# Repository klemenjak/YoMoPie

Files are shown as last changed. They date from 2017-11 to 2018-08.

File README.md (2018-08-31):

# Servus!

Computational methods for the enhancement of energy efficiency rely on a measurement process with sufficient accuracy and number of measurements. Networked energy meters, energy monitors, serve as a vital link between the energy consumption of households and key insights that reveal strategies to achieve significant energy savings.
With YoMoPie, we propose a user-oriented energy monitor for the Raspberry Pi platform that aims to enable intelligent energy services in households. YoMoPie measures active as well as apparent power, stores data locally, and integrates a user-friendly Python library. Furthermore, the presented energy monitor allows users to run self-designed services in their home to enhance energy efficiency. Potential services are (but not limited to) residential demand response, immediate user feedback, smart meter data analytics, or energy disaggregation.

<!--- YoMoPie builds on [the work published in [1]](https://link.springer.com/article/10.1007%2Fs00450-014-0290-8#/page-1).
YoMoPie provides the following advancements:

* It doesn't suffer from a data update rate of 1 second
* It stores data locally
* It integrates a new measurement IC that allows poly-phase metering
* It builds on the Raspberry platform
* The YoMoPie Python package enables easy handling -->

## Research Paper on YomoPie

All design files and pieces of software are available free of charge. However, in case you use the PCB design, code, or other material for research purposes, we kindly ask you to cite our peer-reviewed research paper:

* *Title*: YoMoPie: A User-Oriented Energy Monitor to Enhance Energy Efficiency in Households
* *Authors*: Mr. Christoph Klemenjak, Mr. Stefan Jost and Dr. Wilfried Elmenreich
* *Conference*: 2018 IEEE Conference on Technologies for Sustainability (SusTech)

Recommended Citation:
```
@INPROCEEDINGS{klemenjak2018yomopie,
author={C. Klemenjak and S. Jost and W. Elmenreich},
booktitle={2018 IEEE Conference on Technologies for Sustainability (SusTech)},
title={Yo{M}o{P}ie: {A} User-Oriented Energy Monitor to Enhance Energy Efficiency in Households},
year={2018},
volume={},
number={},
pages={},
keywords={},
doi={},
ISSN={},
month={Nov}}
```

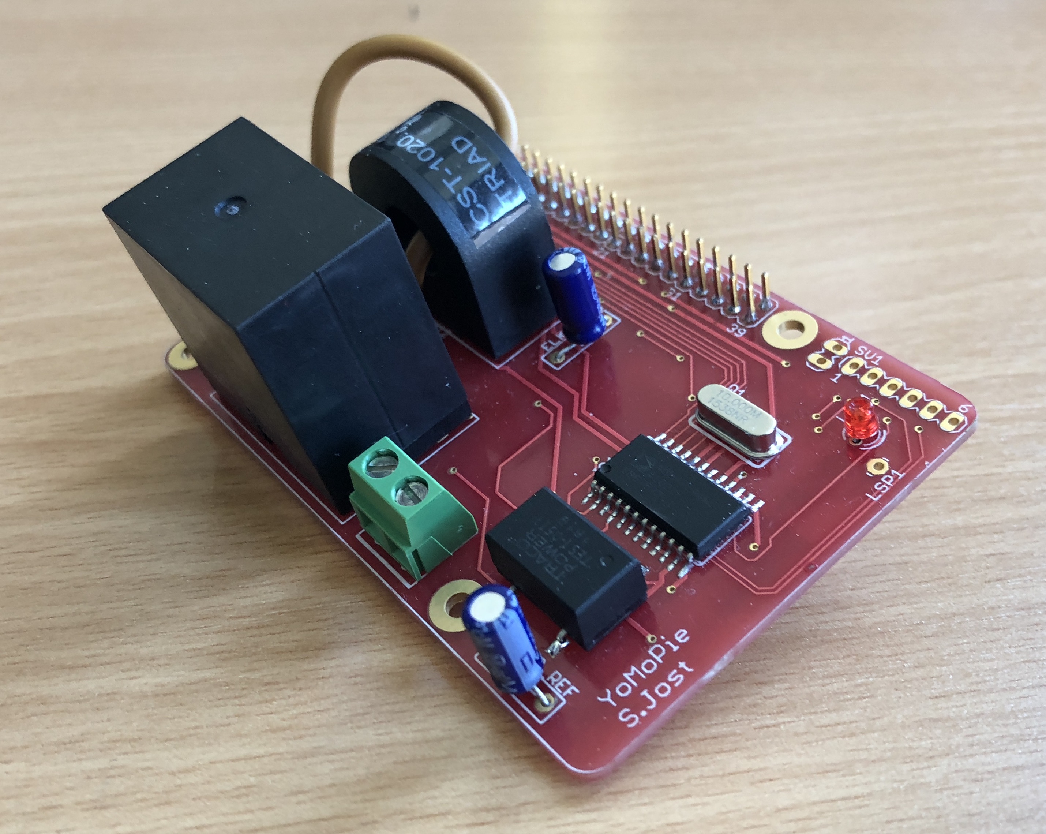
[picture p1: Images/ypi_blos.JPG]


| | YoMoPie  |
| --- | -----:|
|Communication|  WiFi, Ethernet, RF |
|Measurement|  P, Q, S, I, U |
|Number of connections| 1 or 3 |
|Integrated relay |  yes |
|Sampling frequency|  tba. |
|Data update rate |  tba. |
|Power calculation|  Hardware |
|Open-Source|  yes |
|RaspberryPi-compatible|  yes  |
|Costs| approx. 50€  |

Beside a current and a voltage sensor, the board integrates an energy metering chip, the ADE7754. Our library is designed in a way to offer single-phase as well as multi-phase metering.

## Installation

The YoMoPie Python package is available on Python Package Index (PyPI), a repository of software for the Python programming language, and can be installed by issuing one command:

```python
pip3 install YoMoPie
```
Additionally, the entire source code and a manual can be obtained from our YoMoPie Github repository.

## Examples of use

After a successful installation process, the YoMoPie package is available system-wide and can be accessed by a simple import command:
```python
import YoMoPie as yomopie
yp = yomopie.YoMoPie()
```

During initialisation, the number of line conductors has to be set (single or polyphase metering):
```python
yomo.set_lines(1)
```

To test the operation, we recommend to call the function *do_n_measurements*. Based on the number of samples and the sampling period, the function will return first measurement values and saves it into the target file:
```python
yomo.do_n_measurements(number of samples, sampling period, target file)
```

Active power, apparent power, current, and voltage samples can be read with commands such as:
```python
[t, I] = yp.get_irms()
[t, U] = yp.get_vrms()
[t, P] = yp.get_active_energy()
[t, S] = yp.get_apparent_energy()
```
In the same vein, users can activate continuous data logging or perform a fixed amount of subsequent measurements:
```python
yp.do_metering()
yp.do_n_measurements(quantity, rate, file)
```

The operational mode (OPMODE) register defines the general configuration of the integrated measurement chip ADE7754. By writing to this register, A/D converters can be turned on/off, sleep mode can be activated, or a software chip reset can be triggered. For further information, we refer to the datasheet of the measurement chip.

```python
yp.set_operational_mode(OPMODE)
```

# YoMoPie Python package documentation
**[Imports](#imports)**<br>
**[Classvariables](#classvariables)**<br>
**[Methods](#methods)**<br>
*[-init](#init)*<br>
*[-init_yomopie](#init_yomopie)*<br>
*[-set_lines](#set_lines)*<br>
*[-enable_board](#enable_board)*<br>
*[-disable_board](#disable_board)*<br>
*[-chip_reset](#chip_reset)*<br>
*[-write_8bit](#write_8bit)*<br>
*[-read_8bit](#read_8bit)*<br>
*[-write_16bit](#write_16bit)*<br>
*[-read_16bit](#read_16bit)*<br>
*[-read_24bit](#read_24bit)*<br>
*[-get_temp](#get_temp)*<br>
*[-get_laenergy](#get_laenergy)*<br>
*[-get_lappenergy](#get_lappenergy)*<br>
*[-get_period](#get_period)*<br>
*[-set_operational_mode](#set_operational_mode)*<br>
*[-set_measurement_mode](#set_measurement_mode)*<br>
*[-close_SPI_connection](#close_SPI_connection)*<br>
*[-get_aenergy](#get_aenergy)*<br>
*[-get_active_energy](#get_active_energy)*<br>
*[-get_apparent_energy](#get_apparent_energy)*<br>
*[-get_sample](#get_sample)*<br>
*[-get_sampleperperiod](#get_sampleperperiod)*<br>
*[-get_vrms](#get_vrms)*<br>
*[-get_irms](#get_irms)*<br>
*[-do_n_measurements](#do_n_measurements)*<br>
*[-do_metering](#do_metering)*<br>
*[-change_factors](#change_factors)*<br>
*[-reset_factors](#reset_factors)*<br>
*[-init_nrf24](#init_nrf24)*<br>
*[-write_nrf24](#write_nrf24)*<br>
*[-read_nrf24](#read_nrf24)*<br>
**[OPMODE](#opmode)**<br>
**[MMODE](#mmode)**<br>

## Imports
YomoPie requires some additional libraries:

**time**: The time package is required to obtain timestamps.

**math**: YoMoPie requires the math lib for calculations such as reactive energy.

**spidev**: The YoMoPie integrates an energy monitor IC, which communicates via SPI to the RPi. To enable this communication, YoMoPie exploits the spidev lib.

**sys**: This module provides access to some variables used or maintained by the interpreter and to functions that interact strongly with the interpreter.

**RPi.GPIO**: In order to allow further extensions of the YoMoPie eco-system, our package integrates the RPi.GPIO. Also, the reset pin is controlled via GPIO.

**NRF24**: This package allows to utilize the RF module for 2.4 GHz communication.

```python
import time
import math
import spidev
import sys
import RPi.GPIO as GPIO
from lib_nrf24 import NRF24
```
## Class variables

To correctly access the internal registers of the energy monitor IC, several custom variables are required to adjust the register values.

* **read** and **write**: These variables hold the mask that defines the operational mode. Therefore, for reading a register the given address and the **read** variable are the inputs of a bitwise AND operation. On the other hand, for writing to a register the register address and the **write** variable are the inputs of a bitwise OR operation.

* **spi**, **active_lines** and **debug**: These variables hold the SPI object, save the number of active lines, and enable/disable the debug mode.

* **radio**: This object will be used for the RF communication and its functions.
* **sample interval** and **max_f_sample**: defines the time between two samples (with respect to the start_sampling method) in seconds and the maximum sampling frequency (with respect to the sampling error).
* **active_power_LSB**, **apparent_power_LSB**, **vrms_factor** and **irms_factor**: Convert register values to physical quantities and represent permanent conversion factors.

```python
read = 0b00111111
write = 0b10000000
spi=0
radio=0
active_lines = 1
debug = 1

sample_intervall = 1
max_f_sample = 10

active_power_LSB= 0.000013292
apparent_power_LSB= 0.00001024
vrms_factor = 0.000047159
irms_factor = 0.000010807
```

## Methods

In this Section, we describe every method of our  package. A description of function parameters and return values is given.

### __init__

**Description**: This method represents  the constructor and creates a new YoMoPie object.

**Parameters**: None.

**Returns**: Nothing.

```python
def __init__(self):
	self.spi=spidev.SpiDev()
	self.init_yomopie()
	return
```

### init_yomopie

**Description**: Initialises the YoMoPie object. Sets the GPIO mode, disables GPIO warnings and defines pin 19 as output. Also opens a new SPI connection via the SPI device (0,0), sets the SPI speed to 62500 Hz and sets the SPI mode to 1. Finally, the function set_lines is called to set the MMODE, WATMODE and VAMODE.

**Parameters**: None.

**Returns**: Nothing.

```python
def init_yomopie(self):
	GPIO.setmode(GPIO.BCM)
	GPIO.setwarnings(False)
	GPIO.setup(19,GPIO.OUT)
	self.spi.open(0,0)
	self.spi.max_speed_hz = 62500
	self.spi.mode = 0b01
	self.set_lines(self.active_lines)
	self.sampleintervall = 1
	return
```

### set_lines

**Description**: This function sets the number of active phases that will be measured.

**Parameters**:
* lines - Number of phases

**Returns**: Nothing.

```python
def set_lines(self, lines):
	if (lines != 1) and (lines != 3):
		print("Incompatible number of power lines")
		return
	else:
		self.active_lines = lines
		if self.active_lines == 3:
			self.write_8bit(0x0D, 0x3F)
			self.write_8bit(0x0E, 0x3F)
			self.set_measurement_mode(0x70)
		elif self.active_lines == 1:
			self.write_8bit(0x0E, 0x24)
			self.set_measurement_mode(0x10)
			self.write_8bit(0x0D, 0x24)
		return
```

### enable_board

**Description**: Enables the board by pulling pin 19 to HIGH.

**Parameters**: None.

**Returns**: Nothing.

```python
def enable_board(self):
	GPIO.output(19, GPIO.HIGH)
	return
```

### disable_board

**Description**: Disables the board by pulling pin 19 to LOW.

**Parameters**: None.

**Returns**: Nothing.

```python
def disable_board(self):
	GPIO.output(19, GPIO.LOW)
	return
```

### chip_reset

**Description**: Resets the chip to the manufacturer settings

**Parameters**: None.

**Returns**: Nothing.

```python
def chip_reset(self):
	self.write_8bit(0x0A, 0x40)
	time.sleep(1);
	return
```		
### write_8bit    

**Description**: Writes 8 bit to the given address.

**Parameters**:

* register - 8 bit address of the register (see ADE7754 register table)

* value - 8 bit of value that will be written into the register

**Returns**: Nothing.

```python
def write_8bit(self, register, value):
	self.enable_board()
	register = register | self.write
	self.spi.xfer2([register, value])
	return
```

### read_8bit

**Description**: Reads 8 bit of data from the given address.

**Parameters**:
* register - 8 bit address of the register (see ADE7754 register table)

**Returns**: the 8 bit of data in the register as decimal

```python
def read_8bit(self, register):
	self.enable_board()
	register = register & self.read
	result = self.spi.xfer2([register, 0x00])[1:]        
	return result[0]
```

### write_16bit

**Description**: Writes 16 bit to the given address.

**Parameters**:

* register - 8 bit address of the register (see ADE7754 register table)

* value - 16 bit of value that will be written into the register

**Returns**: Nothing.

```python
def write_16bit(self, register, value):
	self.enable_board()
	register = register | self.write
	self.spi.xfer2([register, value[0], value[1]])
	return
```		

### read_16bit  

**Description**: Reads 16 bit of data from the given address.

**Parameters**:
* register - 8 bit address of the register (see ADE7754 register table)

**Returns**: the 16 bit of data in the register as decimal

```python
def read_16bit(self, register):
	self.enable_board()
	register = register & self.read
	result = self.spi.xfer2([register, 0x00, 0x00])[1:]
	dec_result = (result[0]<<8)+result[1]
	return dec_result
```

### read_24bit        

**Description**: Reads 24 bit of data from the given address.

**Parameters**:
* register - 8 bit address of the register (see ADE7754 register table)

**Returns**: the 24 bit of data in the register as decimal

```python
def read_24bit(self, register):
	self.enable_board()
	register = register & self.read
	result = self.spi.xfer2([register, 0x00, 0x00, 0x00])[1:]
	dec_result = (result[0]<<16)+(result[1]<<8)+(result[2])
	return dec_result
```

### get_temp

**Description**: Reads the temperature register (0x08).

**Parameters**: None.

**Returns**: A list [timestamp, temperature in °C]

```python
def get_temp(self):
	reg = self.read_8bit(0x08)
	temp = [time.time(),(reg-129)/4]
	return temp
```

### get_laenergy

**Description**: Reads the active energy register (0x03).

**Parameters**: None.

**Returns**: A list [timestamp, value of the register]

```python
def get_laenergy(self):
	laenergy = [time.time(), self.read_24bit(0x03)]
	return laenergy
```

### get_lappenergy

**Description**: Reads the apparent energy register (0x06).

**Parameters**: None.

**Returns**: A list [timestamp, value of the register]

```python
def get_lappenergy(self):
	lappenergy = [time.time(), self.read_24bit(0x06)]
	return lappenergy
```

### get_period   

**Description**: Reads the period register (0x07).

**Parameters**: None.

**Returns**: A list [timestamp, value of the register]

```python
def get_period(self):
       period = [time.time(), self.read_16bit(0x07)]
       return period
```

### set_operational_mode

**Description**: Sets the OPMODE. For more information see section OPMODE.

**Parameters**:
* value - 8 bit of data representing the OPMODE

**Returns**: Nothing.

```python
def set_operational_mode(self, value):
	self.write_8bit(0x0A, value)
	return
```

### set_measurement_mode

**Description**: Sets the MMODE. For more information see section MMODE.

**Parameters**:
* value - 8 bit of data representing the MMODE

**Returns**: Nothing.

```python
def set_measurement_mode(self, value):
	self.write_8bit(0x0B, value)
	return
```

### close_SPI_connection

**Description**: Closes the SPI connection.

**Parameters**: None.

Returns**: 0 if connection is closed.

```python
def close_SPI_connection(self):
	self.spi.close()
	return 0
```
### get_aenergy

**Description**: Reads the active energy register (0x01).

**Parameters**: None.

**Returns**: A list [timestamp, value of register converted to real value]

```python
def get_aenergy(self):
	aenergy = [time.time(), self.active_power_LSB * self.read_24bit(0x01) *  3600/self.sample_intervall]
	return aenergy
```
### get_active_energy

**Description**: Reads the active energy register (0x02) and resets the register value.

**Parameters**: None.

**Returns**: A list [timestamp, value of register converted to real value]

```python
def get_active_energy(self):
	aenergy =  [time.time(), self.active_power_LSB * self.read_24bit(0x02) *  3600/self.sample_intervall]
	return aenergy
```
### get_apparent_energy

**Description**: Reads the apparent energy register (0x05) and resets the register vlaue.

**Parameters**: None.

**Returns**: A list [timestamp, value of register converted to real value]

```python
def get_apparent_energy(self):
	appenergy = [time.time(), self.apparent_power_LSB * self.read_24bit(0x05)*  3600/self.sample_intervall]
	return appenergy
```
### get_sample

**Description**: Takes one sample and calculates the active energy, apparent energy, reactive energy, VRMS and IRMS.

**Parameters**: None.

**Returns**: A list of 7 elements [timestamp, active energy, apparent energy, reactive energy, period, VRMS, IRMS]

```python
def get_sample(self):
	aenergy = self.get_aenergy()[1] *self.active_factor
	appenergy = self.get_appenergy()[1] *self.apparent_factor
	renergy = math.sqrt(appenergy*appenergy - aenergy*aenergy)
	if self.debug:
		print"Active energy: %f W, Apparent energy: %f VA, Reactive Energy: %f var" %(aenergy, appenergy, renergy)
		print"VRMS: %f IRMS: %f" %(self.get_vrms()[1]*self.vrms_factor,self.get_irms()[1]*self.irms_factor)
	sample = []
	sample.append(time.time())
	sample.append(aenergy)
	sample.append(appenergy)
	sample.append(renergy)
	sample.append(self.get_period()[1])
	sample.append(self.get_vrms()[1]*self.vrms_factor)
	sample.append(self.get_irms()[1]*self.irms_factor)
	return sample
```

### get_vrms

**Description**: Reads the VRMS register depending.

**Parameters**: None.

**Returns**: A list of 2 elements [timestamp, Phase A VRMS] or 4 elements [timestamp, Phase A VRMS, Phase B VRMS, Phase C VRMS]

```python
def get_vrms(self):
	if self.active_lines == 1:
		avrms = [time.time(), self.read_24bit(0x2C)]
		return avrms
	elif self.active_lines == 3:
		vrms = []
		vrms.append(time.time())
		vrms.append(self.read_24bit(0x2C))
		vrms.append(self.read_24bit(0x2D))
		vrms.append(self.read_24bit(0x2E))
		return vrms
	return 0
```

### get_irms

**Description**: Reads the IRMS register.

**Parameters**: None.

**Returns**: A list of 2 elements [timestamp, Phase A IRMS] or 4 elements [timestamp, Phase A IRMS, Phase B IRMS, Phase C IRMS]

```python
def get_irms(self):
	if self.active_lines == 1:
		airms = [time.time(), self.read_24bit(0x29)]
		return airms
	elif self.active_lines == 3:
		irms = []
		irms.append(time.time())
		irms.append(self.read_24bit(0x29))
		irms.append(self.read_24bit(0x2A))
		irms.append(self.read_24bit(0x2B))
		return vrms
	return 0
```

### get_sampleperperiod

**Description**: Reads multiple register and returns the values adjusted to the sampling frequency. This function will be used in the do_n_measurements
 function.

**Parameters**:
* samplerate - the actual samplerate

**Returns**: A list of 7 elements [timestamp, active energy, apparent energy, reactive energy, period, VRMS, IRMS]

```python
def get_sampleperperiod(self, samplerate):
	aenergy = self.get_aenergy()[1] *self.active_factor * 3600/samplerate
	appenergy = self.get_appenergy()[1] *self.apparent_factor * 3600/samplerate
	renergy = math.sqrt(abs(appenergy*appenergy - aenergy*aenergy))
	vrms = self.get_vrms()[1]*self.vrms_factor
	irms = self.get_irms()[1]*self.irms_factor
	if self.debug:
		print("Active energy: %f W, Apparent energy: %f VA, Reactive Energy: %f var" % (aenergy, appenergy, renergy))
		print("VRMS: %f IRMS: %f" %(vrms,irms))
	sample = []
	sample.append(time.time())
	sample.append(aenergy)
	sample.append(appenergy)
	sample.append(renergy)
	sample.append(self.get_period()[1])
	sample.append(vrms)
	sample.append(irms)
	return sample
```

### do_n_measurements

**Description**: Takes *nr_samples* with sampling period *samplerate* and saves the measurements into the give file.

**Parameters**:

* nr_samples - this are the number of samples that will be taken, integer greater then 0
* samplerate - this is the time between each sample, integer greater then 0
* file - this will be the path and name of the file, where the date will be stored

**Returns**: A list of samples (each sample is a list of 7 elements)

```python
def do_n_measurements(self, nr_samples, samplerate, file):
	if (samplerate<1) or (nr_samples<1):
		return 0
	self.sample_intervall = samplerate
	samples = []
	for i in range(0, nr_samples):
		for j in range(0, samplerate):
			time.sleep(1)
	sample = self.get_sampleperperiod(samplerate)
	samples.append(sample)
	logfile = open(file, "a")
	for value in sample:
		logfile.write("%s; " % value)
	logfile.write("\n")
	logfile.close()
	return samples
```

### do_metering

**Description**: Starts a sampling process and saves the data into a file.

**Parameters**:

* f_sample - the sampling frequency (<= 10, but if max_f_sample is changed, this value can be up to 100 with a higher error)
* file - this will be the path and name of the file, where the date will be stored. If this parameter is empty the data will be stored in "smart_meter_output.csv".

**Returns**: Nothing.

```python
def do_metering(self, f_sample, file):
	if (f_sample > max_f_sample):
		print('Incompatible sampling frequency!')
		return 1
	if (file == ''):
		file = 'smart_meter_output.csv'
	for i in range(0,86400):
		sample = []
		sample.append(time.time())
		sample.append(i)
		sample.append(self.get_active_energy())
		sample.append(self.get_apparent_energy())
		data_file = open(file,'a')
		for value in sample:
			logfile.write("%s; " % value)
		logfile.write("\n")
		##print(sample)
		time.sleep(1/f_sample);
	return 0
```

### change_factors

**Description**: Changes the multiplication factors for the register values.

**Parameters**:

* active_f - this is the factor for the active energy calculation
* apparent_f - this is the factor for the apparent energy calculation
* vrms_f - this is the factor for the vrms calculation
* irms_f  this is the factor for the irms calculation

**Returns**: Nothing.

```python
def change_factors(self, active_f, apparent_f, vrms_f, irms_f):
	self.active_power_LSB = active_f
	self.apparent_power_LSB = apparent_f
	self.vrms_factor = vrms_f
	self.irms_factor = irms_f
	return
```

### reset_factors

**Description**: Resets the multiplication factors to the default values. The default values are calculated by our measurements with calibrated equipment.

**Parameters**: None.

**Returns**: Nothing.

```python
def reset_factors(self):
	self.active_power_LSB= 0.000013292
	self.apparent_power_LSB= 0.00001024
	self.vrms_factor = 0.000047159
	self.irms_factor = 0.000010807
	return
```

### init_nrf24

**Description**: Initializes the RF communication via the NRF24 chip.

**Parameters**: None.

**Returns**: Nothing.

```python
def init_nrf24(self):
	pipes = [[0xe7, 0xe7, 0xe7, 0xe7, 0xe7], [0xc2, 0xc2, 0xc2, 0xc2, 0xc2]]

	self.radio = NRF24(GPIO, self.spi)
	self.radio.begin(1, 13)
	self.radio.setPayloadSize(32)
	self.radio.setChannel(0x60)

	self.radio.setDataRate(NRF24.BR_2MBPS)
	self.radio.setPALevel(NRF24.PA_MIN)
	self.radio.setAutoAck(True)
	self.radio.enableDynamicPayloads()
	self.radio.enableAckPayload()
	self.radio.openWritingPipe(pipes[1])
	self.radio.openReadingPipe(1, pipes[0])
	self.radio.printDetails()
	return
```

### write_nrf24

**Description**: Sends a message via the RF communication.

**Parameters**:
* command - the message that will be written via RF

**Returns**: Nothing.

```python
def write_nrf24(self, command):
	message = []
	message = list(command)
	self.radio.write(message)
	print("Send: {}".format(message))

	if self.radio.isAckPayloadAvailable():
		pl_buffer = []
		self.radio.read(pl_buffer, self.radio.getDynamicPayloadSize())
		print(pl_buffer)
		print("Translating the acknowledgment to unicode chars...")
		string = ""
		for n in pl_buffer:
			if(n >= 32 and n <= 126):
			string += chr(n)
		print(string)
	return
```

### read_nrf24

**Description**: Reads a message via the RF communication.

**Parameters**: None.

**Returns**: Nothing.

```python
def read_nrf24(self):
	print("Ready to receive data...")
	self.radio.startListening()
	pipe = [0]
	while not self.radio.available(pipe):
		time.sleep(1/100)
	receivedMessage = []
	self.radio.read(receivedMessage, self.radio.getDynamicPayloadSize())

	print("Translating the receivedMessage to unicode chars...")
	string = ""
	for n in receivedMessage:
		if (n >= 32 and n <= 126):
			string += chr(n)
		print("Our sensor sent us: {}".format(string))
	self.radio.stopListening()
	return
```
## OPMODE
The operational mode (OPMODE) register defines the general configuration of the ADE7754 chip. For detailed information about the individual bits of this register we refer to [Table IX](https://github.com/klemenjak/YoMoPie/blob/master/Datasheets/ADE7754.pdf).

## MMODE
The configuration of period and peak measurements are defined by writing to the MMODE register (0x0B). For more information about the register we refer to [Table XII](https://github.com/klemenjak/YoMoPie/blob/master/Datasheets/ADE7754.pdf).

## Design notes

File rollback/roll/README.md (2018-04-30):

YoMoPie Github Readme

# Welcome to YoMoPie !

The YoMo project aims to empower people using low-cost open hardware smart meters in their household.
With YoMoPie, we provide a Smart Metering extension board for Raspberry Pi. YomoPie comes with a Python library that allows users to easily control and apply this special Smart Metering board.

The YoMoPie builds [on the work published in [1]](https://link.springer.com/article/10.1007%2Fs00450-014-0290-8#/page-1). The board integrates several sensors such as an energy metering IC, a relay to control connected loads, and an interface for RF communication. In contrast to the original YoMo, the YoMoPie utilises the ADE77554 chip, which supports three-phase metering. Our library is designed in a way to offer single-phase as well as multi-phase metering.

| | YoMo v1 | YoMoPie  |
| --- |:---:| -----:|
|Communication| WiFi | WiFi, Ethernet, RF |
|Measurement| P,Q,S,I,V,E | P,Q,S,I,V,E |
|Number of connections| 1 | 3 |
|Switchable| yes | yes |
|Sampling frequency| 1Hz | 1 Hz |
|Power calculation| Hardware | Hardware |
|Open-Source| yes | yes |
|Arduino-based| yes | no  |
|RaspberryPi-compatible| no | yes  |
|Costs|€65|  |

# Examples of use

In order to start using YoMoPie, all the user needs to do is importing the Python library:

```python
import YoMoPie
```

After a successful import, the YoMoPie object can be created and initialised:

```python
yomo = yomopi.YoMoPie()
```

By setting the *set_lines' variable, the user can switch between single and multi-phase metering mode:

```python
yomo.set_lines(1)
```

To test the operation, we recommend to call the function *do_n_measurements*. Based on the number of samples and the sampling period, the function will return first measurement values:

```python
yomo.do_n_measurements(number of samples, sampling period)
```

# YoMoPie Python package documentation
**[Imports](#imports)**<br>
**[Classvariables](#classvariables)**<br>
**[Methods](#methods)**<br>
*[-init](#init)*<br>
*[-init_yomopie](#init_yomopie)*<br>
*[-set_lines](#set_lines)*<br>
*[-enable_board](#enable_board)*<br>
*[-disable_board](#disable_board)*<br>
*[-write_8bit](#write_8bit)*<br>
*[-read_8bit](#read_8bit)*<br>
*[-read_16bit](#read_16bit)*<br>
*[-read_24bit](#read_24bit)*<br>
*[-get_temp](#get_temp)*<br>
*[-get_aenergy](#get_aenergy)*<br>
*[-get_appenergy](#get_appenergy)*<br>
*[-get_period](#get_period)*<br>
*[-set_opmode](#set_opmode)*<br>
*[-set_mmode](#set_mmode)*<br>
*[-get_sample](#get_sample)*<br>
*[-get_vrms](#get_vrms)*<br>
*[-get_irms](#get_irms)*<br>
*[-do_n_measurements](#do_n_measurements)*<br>
*[-change_factors](#change_factors)*<br>
*[-reset_factors](#reset_factors)*<br>
*[-close](#close)*<br>
**[OPMODE](#opmode)**<br>
**[MMODE](#mmode)**<br>

## Imports
YomoPie requires some additional libraries:

**time**: The time package is required to obtain timestaps.

**math**: YoMoPie requires the math lib for calculations such as reactive energy.

**spidev**: The YoMoPie integrates an energy monitor IC, which communicates via SPI to the RPi. To enable this communication, YoMoPie exploits the spidev lib.

**sys**:

**RPi.GPIO**: In order to allow further extensions of the YoMoPie eco system, our package integrates the RPi.GPIO. Also, the reset pin is controlled via GPIO.

```python
import time
import math
import spidev
import sys
import RPi.GPIO as GPIO
```
## Class variables

To correctly access the internal registers of the energy monitor IC, several custom variables are required to adjust the register values.

* **read** and **write**: These variables hold the mask that defines the operational mode. Therefore, for reading a register the given address and the **read** variable are the inputs of a bitwise AND operation. On the other hand, for writing to a register the register address and the **write** variable are the inputs of a bitwise OR operation.

* **spi**, **active_lines** and **debug**: These variables hold the SPI object, save the number of active lines, and enable/disable the debug mode.

* **sample interval** defines the time between two samples (with respect to the start_sampling method) in seconds
* **active_factor**, **apparent_factor**, **vrms_factor** and **irms_factor**: Convert register values to physical quantities and represent permanent conversion factors.

```python
read = 0b00111111
write = 0b10000000
spi=0
active_lines = 1
debug = 1

sampleintervall = 1
active_factor = 1
apparent_factor = 1
vrms_factor = 1
irms_factor = 1
```

## Methods

In this Section, we describe every method of our  package. A description of function parameters and return values is given.

### __init__

**Description**: This method represents  the constructor and creates a new YoMoPie object.

**Parameters**: None.

**Returns**: Nothing.

```python
def __init__(self):
       self.spi=spidev.SpiDev()
       try:
			self.init_yomopie()
		except Error as err:
			print("Unexpected error:", format(err.args))
			return 0
        return
```

### init_yomopie

**Description**: Initialises the YoMoPie object. Sets the GPIO mode, disables GPIO warnings and defines pin 19 as output. Also opens a new SPI connection via the SPI device (0,0), sets the SPI speed to 62500 Hz and sets the SPI mode to 1. Finally, the function set_lines is called to set the MMODE, WATMODE and VAMODE.

**Parameters**: None.

**Returns**: Nothing.

```python
def init_yomopie(self):
    GPIO.setmode(GPIO.BCM)
       GPIO.setwarnings(False)
       GPIO.setup(19,GPIO.OUT)
       self.spi.open(0,0)
       self.spi.max_speed_hz = 62500
       self.spi.mode = 0b01
    self.set_lines(self.active_lines)
       return
```

### set_lines

**Description**: This function sets the number of active phases that will be measured.

**Parameters**: 
* lines - Number of phases

**Returns**: Nothing.

```python
def set_lines(self, lines):
    if (lines != 1) and (lines != 3):
           print "Wrong number of lines"
                return
    else:
               self.active_lines = lines
                if self.active_lines == 3:
            self.write_8bit(0x0D, 0x3F)
                    self.write_8bit(0x0E, 0x3F)
            self.set_mmode(0x70)
                elif self.active_lines == 1:
                    self.write_8bit(0x0D, 0x24)
                    self.write_8bit(0x0E, 0x24)
                    self.set_mmode(0x10)                
        return
    return
```

### enable_board

**Description**: Enables the board by pulling pin 19 to HIGH.

**Parameters**: None.

**Returns**: Nothing.

```python
def enable_board(self):
    GPIO.output(19, GPIO.HIGH)
    return
```

### disable_board

**Description**: Disables the board by pulling pin 19 to LOW.

**Parameters**: None.

**Returns**: Nothing.

```python
def disable_board(self):
       GPIO.output(19, GPIO.LOW)
       return
```

### write_8bit    

**Description**: Writes 8 bit to the given address.

**Parameters**:

* register - 8 bit address of the register (see ADE7754 register table)

* value - 8 bit of value that will be written into the register

**Returns**: Nothing.

```python
def write_8bit(self, register, value):
       self.enable_board()
       register = register | self.write
       self.spi.xfer2([register, value])
       return
```

### read_8bit

**Description**: Reads 8 bit of data from the given address.

**Parameters**: 
* register - 8 bit address of the register (see ADE7754 register table)

**Returns**: the 8 bit of data in the register as decimal

```python
def read_8bit(self, register):
       self.enable_board()
       register = register & self.read
       result = self.spi.xfer2([register, 0x00])[1:]        
       return result[0]
```

### read_16bit  

**Description**: Reads 16 bit of data from the given address.

**Parameters**: 
* register - 8 bit address of the register (see ADE7754 register table)

**Returns**: the 16 bit of data in the register as decimal

```python
def read_16bit(self, register):
       self.enable_board()
       register = register & self.read
       result = self.spi.xfer2([register, 0x00, 0x00])[1:]
       dec_result = (result[0]<<8)+result[1]
       return dec_result
```

### read_24bit        

**Description**: Reads 24 bit of data from the given address.

**Parameters**: 
* register - 8 bit address of the register (see ADE7754 register table)

**Returns**: the 24 bit of data in the register as decimal

```python
def read_24bit(self, register):
       self.enable_board()
       register = register & self.read
       result = self.spi.xfer2([register, 0x00, 0x00, 0x00])[1:]
       dec_result = (result[0]<<16)+(result[1]<<8)+(result[0])
       return dec_result
```

### get_temp

**Description**: Reads the temperature register (0x08).

**Parameters**: None.

**Returns**: A list [timestamp, temperature in °C]

```python
def get_temp(self):
       reg = self.read_8bit(0x08)
       temp = [time.time(),(reg-129)/4]
       return temp
```

### get_aenergy

**Description**: Reads the active energy register (0x02) and resets the register.

**Parameters**: None.

**Returns**: A list [timestamp, value of the register]

```python
def get_aenergy(self):
       aenergy = [time.time(), self.read_24bit(0x02)]
       return aenergy
```

### get_appenergy

**Description**: Reads the apparent energy register (0x05) and resets the register.

**Parameters**: None.

**Returns**: A list [timestamp, value of the register]

```python
def get_appenergy(self):
    appenergy = [time.time(), self.read_24bit(0x05)]
        return appenergy
```

### get_period   

**Description**: Reads the period register (0x07).

**Parameters**: None.

**Returns**: A list [timestamp, value of the register]

```python
def get_period(self):
       period = [time.time(), self.read_16bit(0x07)]
       return period
```

### set_opmode

**Description**: Sets the OPMODE. For more information see section OPMODE.

**Parameters**: 
* value - 8 bit of data representing the OPMODE

**Returns**: Nothing.

```python
def set_opmode(self, value):
    self.write_8bit(0x0A, value)
        return
```

### set_mmode

**Description**: Sets the MMODE. For more information see section MMODE.

**Parameters**: 
* value - 8 bit of data representing the MMODE

**Returns**: Nothing.

```python
def set_mmode(self, value):
    self.write_8bit(0x0B, value)
        return
```

### get_sample

**Description**: Takes one sample and calculates the active energy, apparent energy, reactive energy, VRMS and IRMS.

**Parameters**: None.

**Returns**: A list of 7 elements [timestamp, active energy, apparent energy, reactive energy, period, VRMS, IRMS]

```python
def get_sample(self):
        aenergy = self.get_aenergy()[1] *self.active_factor
        appenergy = self.get_appenergy()[1] *self.apparent_factor
        renergy = math.sqrt(appenergy*appenergy - aenergy*aenergy)
        if self.debug:
            print"Active energy: %f W, Apparent energy: %f VA, Reactive Energy: %f var"
        % (aenergy, appenergy, renergy)
            print"VRMS: %f IRMS: %f"
        %(self.get_vrms()[1]*self.vrms_factor,self.get_irms()[1]*self.irms_factor)
        sample = []
        sample.append(time.time())
        sample.append(aenergy)
        sample.append(appenergy)
        sample.append(renergy)
        sample.append(self.get_period()[1])
        sample.append(self.get_vrms()[1]*self.vrms_factor)
        sample.append(self.get_irms()[1]*self.irms_factor)
        return sample
```

### get_vrms

**Description**: Reads the VRMS register depending.

**Parameters**: None.

**Returns**: A list of 2 elements [timestamp, Phase A VRMS] or 4 elements [timestamp, Phase A VRMS, Phase B VRMS, Phase C VRMS]

```python
def get_vrms(self):
        if self.active_lines == 1:
            avrms = [time.time(), self.read_24bit(0x2C)]
            return avrms
        elif self.active_lines == 3:
              vrms = []
              vrms.append(time.time())
            vrms.append(self.read_24bit(0x2C))
            vrms.append(self.read_24bit(0x2D))
            vrms.append(self.read_24bit(0x2E))
            return vrms
    return 0
```

### get_irms

**Description**: Reads the IRMS register.

**Parameters**: None.

**Returns**: A list of 2 elements [timestamp, Phase A IRMS] or 4 elements [timestamp, Phase A IRMS, Phase B IRMS, Phase C IRMS]

```python
def get_irms(self):
        if self.active_lines == 1:
            airms = [time.time(), self.read_24bit(0x29)]
            return airms
        elif self.active_lines == 3:
              irms = []
              irms.append(time.time())
            irms.append(self.read_24bit(0x29))
            irms.append(self.read_24bit(0x2A))
            irms.append(self.read_24bit(0x2B))
            return vrms
        return 0
```

### do_n_measurements

**Description**: Takes *nr_samples* with sampling period *samplerate* and saves the measurements into the samples.log file.

**Parameters**:

* nr_samples - this are the number of samples that will be taken, integer greater then 0
* samplerate - this is the time between each sample, integer greater then 0

**Returns**: A list of samples (each sample is a list of 7 elements)

```python
def do_n_measurements(self, nr_samples, samplerate):
	if (samplerate<1) or (nr_samples<1):
		return 0
	self.sampleintervall = samplerate
	samples = []
	for i in range(0, nr_samples):
		for j in range(0, samplerate):
			time.sleep(1)
		sample = self.get_sample()
		samples.append(sample)
		logfile = open("samples.log", "a")
		for value in sample:
			logfile.write("%s, " % value)
		logfile.write("\n")
		logfile.close()
	return samples
```

### change_factors

**Description**: Changes the multiplication factors for the register values.

**Parameters**:

* apparent_f - this is the factor for the apparent energy calculation
* vrms_f - this is the factor for the vrms calculation
* irms_f  this is the factor for the irms calculation

**Returns**: Nothing.

```python
def change_factors(self, apparent_f, vrms_f, irms_f):
	self.apparent_factor = apparent_f
	self.vrms_factor = vrms_f
	self.irms_factor = irms_f
	return
```

### reset_factors

**Description**: Resets the multiplication factors to the default values. The default values are calculated by our measurements with calibrated equipment.

**Parameters**: None.

**Returns**: Nothing.	

```python
def reset_factors(self):
	self.apparent_factor = 1
	self.vrms_factor = 1
	self.irms_factor = 1
	return
``` 

### close

**Description**: Closes the SPI connection between the Raspberry Pi and the YoMoPie.

**Parameters**: None.

**Return**: Nothing.

```python
def close(self):
    self.spi.close()
    return
```

## OPMODE
The operational mode (OPMODE) register defines the general configuration of the ADE7754 chip. For detailed information about the individual bits of this register we refer to [Table IX](https://github.com/klemenjak/YoMoPie/blob/master/Datasheets/ADE7754.pdf).

## MMODE
The configuration of period and peak measurements are defined by writing to the MMODE register (0x0B). For more information about the register we refer to [Table XII](https://github.com/klemenjak/YoMoPie/blob/master/Datasheets/ADE7754.pdf).

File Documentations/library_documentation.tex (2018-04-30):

\documentclass{scrartcl}  % Was möchte ich schreiben scrartcl--> Artikel

\usepackage[utf8x]{inputenc}  % Umlaute etc. im Input-File
\usepackage[T1]{fontenc}	% Datestellung der Umlaute im Ouput-File
\usepackage{lmodern}	% für bessere Darstellung im Pdf
\usepackage{amsmath, amssymb, amstext, amsthm}
\usepackage{hyperref}	%aktiviert Hyperrefs
\usepackage{threeparttable}
\usepackage{graphicx}
\usepackage{wrapfig}
\usepackage{array}
\usepackage{float}
\usepackage{underscore}
\usepackage{listings}

\lstset{language=Python}
\lstset{basicstyle=\footnotesize}
\setlength{\parindent}{0em}

\usepackage[naustrian]{babel}	% Rechtschreibung für Österreichisch aktivieren

\title{YoMoPi - Library}
\author{Stefan Jost}

\usepackage[automark]{scrpage2}	% Kopf und Fußzeile hinzufügen
\pagestyle{scrheadings}
\clearscrheadfoot
\ifoot[\pagemark]{\pagemark}
\ofoot[YoMoPi - Library]{YoMoPi - Library}
\chead[YoMoPi - Library]{YoMoPi - Library}

\begin{document}

\maketitle  % Titel erzeugen mit den oben angeführten Parametern
\newpage
\tableofcontents
\newpage

\section{Imports}
Following imports were needed for this library.

\textbf{time}: time was needed to get the timestamp on each value.

\textbf{math}: math was needed to calculate the squareroot for the reactive energy.

\textbf{spidev}: the spidev module was needed to use the SPI on the Raspberry Pi

\textbf{sys}: 

\textbf{RPi.GPIO}: the RPi.GPIO was needed to controll the GPIO pins for the reset pin and further extentions

\begin{lstlisting}
import time
import math
import spidev
import sys
import RPi.GPIO as GPIO 
\end{lstlisting}
 
\section{Classvariables}

Following variable were needed to correcty access the register and to adjust the register values to usefull values. 

\textbf{read} and \textbf{write}: the read and write were needed to mask the register address to not accidently write the register instead of reading it. Therefor to read a register the given address will be bitwise AND masked with the \textbf{read} variable and to write a register the address will be bitwise OR masked with the \textbf{write} variable.

\textbf{spi}, \textbf{active_lines} and \textbf{debug}: this variables were used to save the spi object, to save the number of actives phases that will be measured and to enable debugging via the console.

\textbf{sampleintervall}, \textbf{active_factor}, \textbf{apparent_factor}, \textbf{vrms_factor} and \textbf{irms_factor}: the sampleintervall defines the time between each sample when the start_sampling method is called. The minimum time between each sample is 1 second. Sampleintervall defines the number of seconds and can take each integer value greater then 0. The different factor variables will adjust the values read from the registers. This factors can be changes but should not be changed because they are calibrated values.
\begin{lstlisting}
read = 0b00111111
write = 0b10000000
spi=0
active_lines = 1
debug = 1
	
sampleintervall = 1
active_factor = 1
apparent_factor = 1
vrms_factor = 1
irms_factor = 1
\end{lstlisting}
    
\section{Methods}

In this section every method from the library is listed and you will find a detailed description on the parameters and returns of each function. For more information you will also find the full source code of the function.
\subsection{__init__}

\textbf{Description}: This is the constructor and it creates a new YoMoPi object. It also creates a new SPI objects for each YoMoPi object.

\textbf{Parameters}: None.

\textbf{Returns}: Nothing.
\begin{lstlisting}
def __init__(self):
       self.spi=spidev.SpiDev()
       return 
\end{lstlisting}
 
\subsection{init_yomopi}

\textbf{Description}: Initializes the YoMoPi object. Sets the GPIO mode, disables GPIO warnings and defines pin 19 as output. Also opens a new SPI connection via the SPI device (0,0), sets the SPI speed to 62500 Hz and sets the SPI mode to 1. Finaly the function set_lines is called to set the MMODE, WATMODE and VAMODE.

\textbf{Parameters}: None.

\textbf{Returns}: Nothing.

\begin{lstlisting}
def init_yomopi(self):
	GPIO.setmode(GPIO.BCM)
       GPIO.setwarnings(False)
       GPIO.setup(19,GPIO.OUT)
       self.spi.open(0,0)
       self.spi.max_speed_hz = 62500
       self.spi.mode = 0b01
	self.set_lines(self.active_lines)
       return 
\end{lstlisting}
		
\subsection{set_lines}

\textbf{Description}: This function sets the number of active phases that will be measured.

\textbf{Parameters}: lines - 1 or 3

\textbf{Returns}: Nothing.
\begin{lstlisting}
def set_lines(self, lines):
	if (lines != 1) and (lines != 3):
       	print "Wrong number of lines"
            	return
	else:
           	self.active_lines = lines
            	if self.active_lines == 3:
			self.write_8bit(0x0D, 0x3F)
                	self.write_8bit(0x0E, 0x3F)
			self.set_mmode(0x70)
            	elif self.active_lines == 1:
            		self.write_8bit(0x0D, 0x24)
            		self.write_8bit(0x0E, 0x24)	
            		self.set_mmode(0x10)				
		return
	return
\end{lstlisting}

\subsection{enable_board}

\textbf{Description}: Enables the board by pulling pin 19 into the HIGH state.

\textbf{Parameters}: None.

\textbf{Returns}: Nothing.

\begin{lstlisting}	
def enable_board(self):
	GPIO.output(19, GPIO.HIGH)
	return
\end{lstlisting}

\subsection{disable_board}

\textbf{Description}: Disables the board by pulling pin 19 into the LOW state.

\textbf{Parameters}: None.

\textbf{Returns}: Nothing.

\begin{lstlisting}
def disable_board(self):
       GPIO.output(19, GPIO.LOW)
       return
\end{lstlisting}

\subsection{write_8bit}    

\textbf{Description}: Writes 8 bit of data to the given address.

\textbf{Parameters}: register - 8 bit address of the register (see ADE7754 register table)

					value - 8 bit of value that will be written into the register

\textbf{Returns}: Nothing.

\begin{lstlisting}
def write_8bit(self, register, value):
       self.enable_board()
       register = register | self.write
       self.spi.xfer2([register, value])
       return
\end{lstlisting}

\subsection{read_8bit}

\textbf{Description}: Reads 8 bit of data from the given address.

\textbf{Parameters}: register - 8 bit address of the register (see ADE7754 register table)

\textbf{Returns}: the 8 bit of data in the register as decimal

\begin{lstlisting}
def read_8bit(self, register):
       self.enable_board()
       register = register \& self.read
       result = self.spi.xfer2([register, 0x00])[1:]        
       return result[0]
\end{lstlisting}
 
\subsection{read_16bit}   

\textbf{Description}: Reads 16 bit of data from the given address.

\textbf{Parameters}: register - 8 bit address of the register (see ADE7754 register table)

\textbf{Returns}: the 16 bit of data in the register as decimal
  
\begin{lstlisting}
def read_16bit(self, register):
       self.enable_board()
       register = register \& self.read
       result = self.spi.xfer2([register, 0x00, 0x00])[1:]
       dec_result = (result[0]<<8)+result[1]
       return dec_result
\end{lstlisting}

\subsection{read_24bit}        

\textbf{Description}: Reads 24 bit of data from the given address.

\textbf{Parameters}: register - 8 bit address of the register (see ADE7754 register table)

\textbf{Returns}: the 24 bit of data in the register as decimal

\begin{lstlisting}
def read_24bit(self, register):
       self.enable_board()
       register = register \& self.read
       result = self.spi.xfer2([register, 0x00, 0x00, 0x00])[1:]
       dec_result = (result[0]<<16)+(result[1]<<8)+(result[0])
       return dec_result
\end{lstlisting}

\subsection{get_temp}

\textbf{Description}: Reads 8 bit of data from the temperature register (0x08).

\textbf{Parameters}: None.

\textbf{Returns}: A list of two elements [timestamp, temperature in °C]

\begin{lstlisting}
def get_temp(self):
       reg = self.read_8bit(0x08)
       temp = [time.time(),(reg-129)/4]
       return temp
\end{lstlisting}
    
\subsection{get_aenergy}

\textbf{Description}: Reads 24 bit of data from the active ernergy register (0x02) and resets the register to 0.

\textbf{Parameters}: None.

\textbf{Returns}: A list of two elements [timestamp, value of the register]

\begin{lstlisting}
def get_aenergy(self):
       aenergy = [time.time(), self.read_24bit(0x02)]
       return aenergy
\end{lstlisting}

\subsection{get_appenergy}	

\textbf{Description}: Reads 24 bit of data from the apparent ernergy register (0x05) and resets the register to 0.

\textbf{Parameters}: None.

\textbf{Returns}: A list of two elements [timestamp, value of the register]
\begin{lstlisting}	
def get_appenergy(self):
	appenergy = [time.time(), self.read_24bit(0x05)]
    	return appenergy
\end{lstlisting}
 
\subsection{get_period}   

\textbf{Description}: Reads 16 bit of data from the period register (0x07).

\textbf{Parameters}: None.

\textbf{Returns}: A list of two elements [timestamp, value of the register]
\begin{lstlisting}
def get_period(self):
       period = [time.time(), self.read_16bit(0x07)]
       return period
\end{lstlisting}
		
\subsection{set_opmode}

\textbf{Description}: Sets the OPMODE. For more information to the OPMODE see section OPMODE.

\textbf{Parameters}: value - 8 bit of data representing the OPMODE

\textbf{Returns}: Nothing.

\begin{lstlisting}
def set_opmode(self, value):
	self.write_8bit(0x0A, value)
    	return
\end{lstlisting}

\subsection{set_mmode}

\textbf{Description}: Sets the MMODE. For more information to the MMODE see section MMODE.

\textbf{Parameters}: value - 8 bit of data representing the MMODE

\textbf{Returns}: Nothing.

\begin{lstlisting}
def set_mmode(self, value):
	self.write_8bit(0x0B, value)
    	return
\end{lstlisting}

\subsection{get_sample}	

\textbf{Description}: Takes one sample and calculates the active energy, apparent energy, reactive energy, VRMS and IRMS. The calculated values are the real values. (after adjusting with their factores)

\textbf{Parameters}: None.

\textbf{Returns}: A list of 7 elements [timestamp, active energy, apparent energy, reactive energy, period, VRMS, IRMS]

\begin{lstlisting}	
def get_sample(self):
    	aenergy = self.get_aenergy()[1] *self.active_factor
    	appenergy = self.get_appenergy()[1] *self.apparent_factor 
    	renergy = math.sqrt(appenergy*appenergy - aenergy*aenergy)
    	if self.debug:
    		print"Active energy: %f W, Apparent energy: %f VA, Reactive Energy: %f var" 
		% (aenergy, appenergy, renergy)
    		print"VRMS: %f IRMS: %f" 
		%(self.get_vrms()[1]*self.vrms_factor,self.get_irms()[1]*self.irms_factor)
    	sample = []
    	sample.append(time.time())
    	sample.append(aenergy)
    	sample.append(appenergy)
    	sample.append(renergy)
    	sample.append(self.get_period()[1])
    	sample.append(self.get_vrms()[1]*self.vrms_factor)
    	sample.append(self.get_irms()[1]*self.irms_factor)
    	return sample
\end{lstlisting}
		
\subsection{get_vrms}

\textbf{Description}: Reads the VRMS register depending on if the active lines is 1 or 3.

\textbf{Parameters}: None.

\textbf{Returns}: A list of 2 elements [timestamp, Phase A VRMS] or 4 elements [timestamp, Phase A VRMS, Phase B VRMS, Phase C VRMS]

\begin{lstlisting}
def get_vrms(self):
    	if self.active_lines == 1:
    		avrms = [time.time(), self.read_24bit(0x2C)]
    		return avrms
    	elif self.active_lines == 3:
              vrms = []
              vrms.append(time.time())
    		vrms.append(self.read_24bit(0x2C))
    		vrms.append(self.read_24bit(0x2D))
    		vrms.append(self.read_24bit(0x2E))
    		return vrms
	return 0
\end{lstlisting}
		
\subsection{get_irms}

\textbf{Description}: Reads the IRMS register depending on if the active lines is 1 or 3.

\textbf{Parameters}: None.

\textbf{Returns}: A list of 2 elements [timestamp, Phase A IRMS] or 4 elements [timestamp, Phase A IRMS, Phase B IRMS, Phase C IRMS]

\begin{lstlisting}
def get_irms(self):
    	if self.active_lines == 1:
    		airms = [time.time(), self.read_24bit(0x29)]
    		return airms
    	elif self.active_lines == 3:
              irms = []
              irms.append(time.time())
    		irms.append(self.read_24bit(0x29))
    		irms.append(self.read_24bit(0x2A))
    		irms.append(self.read_24bit(0x2B))
    		return vrms
    	return 0
\end{lstlisting}
		
\subsection{start_sampling}	

\textbf{Description}: Starts a sampling programm that takes a number of samples depending on the parameters.

\textbf{Parameters}: nr_samples - this are the number of samples that will be taken, integer greater then 0

					samplerate - this is the time between each sample, integer greater then 0

\textbf{Returns}: A list of samples (each sample is a list of 7 elements)
\begin{lstlisting}
def start_sampling(self, nr_samples, samplerate):
	if (samplerate<1) or (nr_samples<1):
		return 0
	self.sampleintervall = samplerate
	samples = []
	for i in range(0, nr_samples):
            
		for j in range(0, samplerate):
			time.sleep(1)
                
		samples.append(self.get_sample())     
	return samples
\end{lstlisting}
    
\subsection{close}

\textbf{Description}: Closes the SPI connection.

\textbf{Parameters}: None.

\textbf{Returns}: Nothing.

\begin{lstlisting}
def close(self):
	self.spi.close()
	return
\end{lstlisting}

\section{OPMODE}
The general configuration of the ADE7754 is defined by writing to the OPMODE register (0x0A).
\begin{figure}[H]
\centering
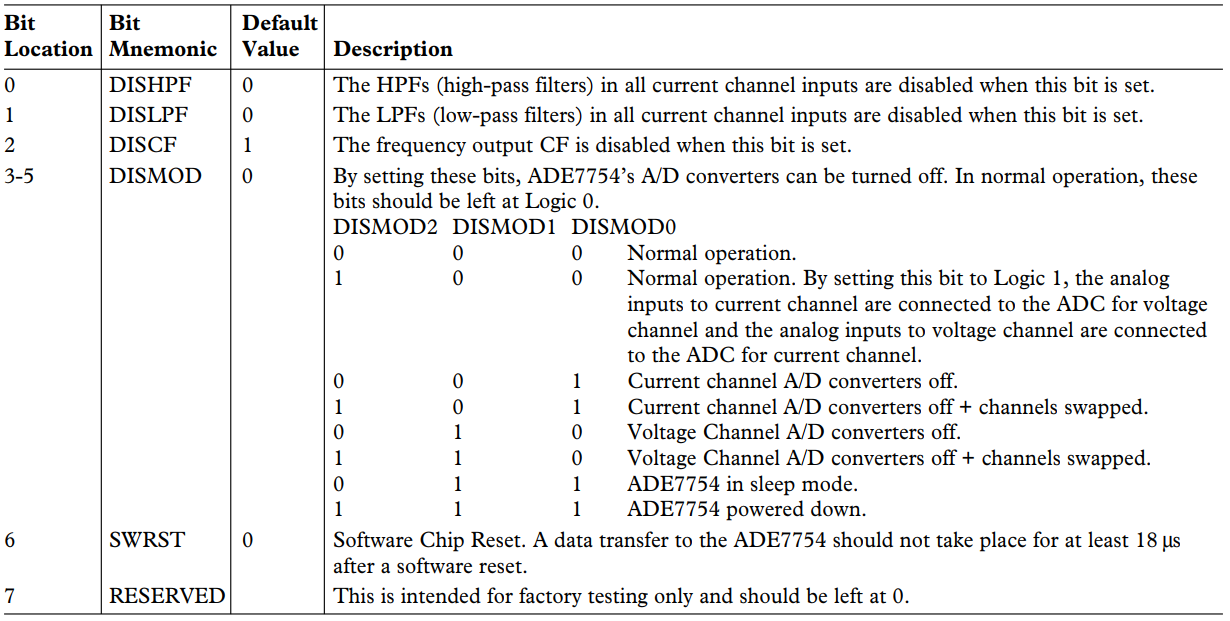
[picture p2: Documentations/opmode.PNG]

\caption{OPMODE}\label{fig:myFigure1}
\end{figure}

\newpage

\section{MMODE}
The configuration of the period and peak measurements made by the ADE7754 are defined by writing to the MMODE register (0x0B).
\begin{figure}[H]
\centering
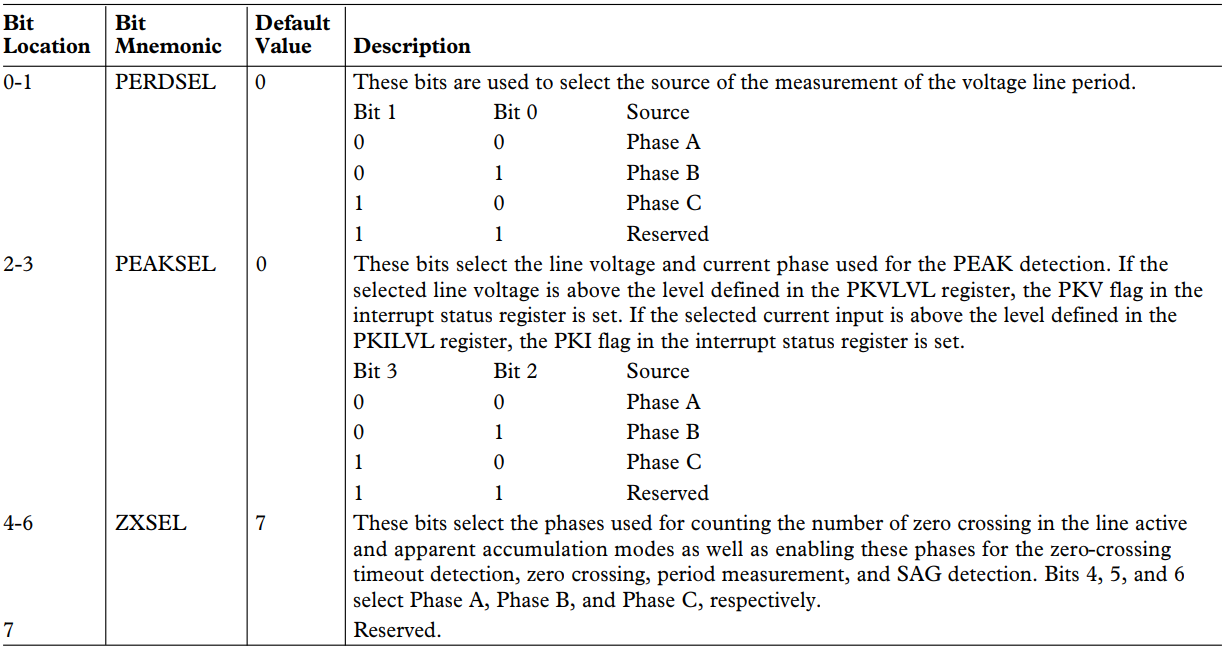
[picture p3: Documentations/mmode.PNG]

\caption{MMODE}\label{fig:myFigure2}
\end{figure}

\section{Examples}
To use the YoMoPi library you first need to import the library.

\begin{lstlisting}
import yomopi
\end{lstlisting}

When the library is correcty imported you can create a new YoMoPi object and initialize is with the init_yomopi function.
\begin{lstlisting}
yomo = yomopi.YoMoPi()
yomo.init_yomopi()
\end{lstlisting}

To test the implementation we start a short sampling. Therefor we call the start_sampling function with 5 samples and a delay of 1 second between each sample.
\begin{lstlisting}
yomo.start_sampling(5, 1)
\end{lstlisting}

If you want to switch the measurement to one phase change the line like this.
\begin{lstlisting}
yomo.set_lines(1)
\end{lstlisting}

\newpage
\listoffigures

\end{document}

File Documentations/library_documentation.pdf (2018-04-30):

YoMoPi - Library

# YoMoPi - Library

## Stefan Jost

## 14. Februar 2018

1 | YoMoPi - Library

## Inhaltsverzeichnis

1 Imports | 3
2 Classvariables | 3
3 Methods | 4
4 OPMODE | 10
5 MMODE | 11
6 Examples | 11
2 | YoMoPi - Library

## 1 Imports

Following imports were needed for this library.
time: time was needed to get the timestamp on each value.
math: math was needed to calculate the squareroot for the reactive energy.
spidev: the spidev module was needed to use the SPI on the Raspberry Pi
sys:
RPi.GPIO: the RPi.GPIO was needed to controll the GPIO pins for the reset pin and further extentions

import time
import math
import s pi d e v
import s y s
import RPi .GPIO a s GPIO

## 2 Classvariables

Following variable were needed to correcty access the register and to adjust the register values to usefull values.
read and write: the read and write were needed to mask the register address to not accidently write the register instead of reading it. Therefor to read a register the given address will be bitwise AND masked with the read variable and to write a register the address will be bitwise OR masked with the write variable.
spi, active_lines and debug: this variables were used to save the spi object, to save the number of actives phases that will be measured and to enable debugging via the console.
sampleintervall, active_factor, apparent_factor, vrms_factor and irms_factor: the sampleintervall defines the time between each sample when the start_sampling method is called. The minimum time between each sample is 1 second. Sampleintervall defines the number of seconds and can take each integer value greater then 0. The dif-ferent factor variables will adjust the values read from the registers. This factors can be changes but should not be changed because they are calibrated values.

re ad = 0 b00111111
w ri t e = 0 b10000000
s p i=0
a c t i v e _ l i n e s = 1 debug = 1

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

## 3 Methods

In this section every method from the library is listed and you will find a detailed description on the parameters and returns of each function. For more information you will also find the full source code of the function.

### 3.1 __init__

Description: This is the constructor and it creates a new YoMoPi object. It also creates a new SPI objects for each YoMoPi object.
Parameters: None.
Returns: Nothing.

def __init__ ( s e l f ) :
s e l f . s p i=s pi d e v . SpiDev ( ) return

### 3.2 init_yomopi

Description: Initializes the YoMoPi object. Sets the GPIO mode, disables GPIO war-nings and defines pin 19 as output. Also opens a new SPI connection via the SPI device (0,0), sets the SPI speed to 62500 Hz and sets the SPI mode to 1. Finaly the function set_lines is called to set the MMODE, WATMODE and VAMODE.
Parameters: None.
Returns: Nothing.

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

### 3.3 set_lines

Description: This function sets the number of active phases that will be measured. Parameters: lines - 1 or 3
Returns: Nothing.

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

s e l f . w ri t e_ 8 bi t ( 0 x0E , 0x3F ) s e l f . set_mmode ( 0 x70 )
e l i f s e l f . a c t i v e _ l i n e s == 1 : s e l f . w ri t e_ 8 bi t ( 0x0D , 0 x24 ) s e l f . w ri t e_ 8 bi t ( 0 x0E , 0 x24 ) s e l f . set_mmode ( 0 x10 )
return
return

### 3.4 enable_board

Description: Enables the board by pulling pin 19 into the HIGH state. Parameters: None.
Returns: Nothing.

def enable_board ( s e l f ) : GPIO. output ( 1 9 , GPIO.HIGH) return

### 3.5 disable_board

Description: Disables the board by pulling pin 19 into the LOW state. Parameters: None.
Returns: Nothing.

def di s able_b o a rd ( s e l f ) :
GPIO. output ( 1 9 , GPIO.LOW) return

### 3.6 write_8bit

Description: Writes 8 bit of data to the given address.
Parameters: register - 8 bit address of the register (see ADE7754 register table) value - 8 bit of value that will be written into the register
Returns: Nothing.

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

### 3.7 read_8bit

Description: Reads 8 bit of data from the given address.
Parameters: register - 8 bit address of the register (see ADE7754 register table) Returns: the 8 bit of data in the register as decimal
5 | YoMoPi - Library

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

### 3.8 read_16bit

Description: Reads 16 bit of data from the given address.
Parameters: register - 8 bit address of the register (see ADE7754 register table) Returns: the 16 bit of data in the register as decimal

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

### 3.9 read_24bit

Description: Reads 24 bit of data from the given address.
Parameters: register - 8 bit address of the register (see ADE7754 register table) Returns: the 24 bit of data in the register as decimal

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

### 3.10 get_temp

Description: Reads 8 bit of data from the temperature register (0x08). Parameters: None.
Returns: A list of two elements [timestamp, temperature in ◦C]

def get_temp ( s e l f ) :
r e g = s e l f . re ad_ 8bi t ( 0 x08 )
temp = [ time . time ( ) , ( reg −129)/4] return temp

### 3.11 get_aenergy

Description: Reads 24 bit of data from the active ernergy register (0x02) and resets the register to 0.
Parameters: None.
Returns: A list of two elements [timestamp, value of the register]
6 | YoMoPi - Library

def get_aenergy ( s e l f ) :
aene r gy = [ time . time ( ) , s e l f . re ad_ 2 4bi t ( 0 x02 ) ] return aene r gy

### 3.12 get_appenergy

Description: Reads 24 bit of data from the apparent ernergy register (0x05) and resets the register to 0.
Parameters: None.
Returns: A list of two elements [timestamp, value of the register]

def get_appenergy ( s e l f ) :
appenergy = [ time . time ( ) , s e l f . re ad_ 2 4bi t ( 0 x05 ) ] return appenergy

### 3.13 get_period

Description: Reads 16 bit of data from the period register (0x07). Parameters: None.
Returns: A list of two elements [timestamp, value of the register]

def ge t_pe ri od ( s e l f ) :
p e ri o d = [ time . time ( ) , s e l f . re ad_ 1 6bi t ( 0 x07 ) ]
return p e ri o d

### 3.14 set_opmode

Description: Sets the OPMODE. For more information to the OPMODE see section OPMODE.
Parameters: value - 8 bit of data representing the OPMODE
Returns: Nothing.

def set_opmode ( s e l f , v al u e ) :
s e l f . w ri t e_ 8 bi t ( 0 x0A , v al u e ) return

### 3.15 set_mmode

Description: Sets the MMODE. For more information to the MMODE see section MMODE.
Parameters: value - 8 bit of data representing the MMODE
Returns: Nothing.

def set_mmode ( s e l f , v al u e ) :
s e l f . w ri t e_ 8 bi t ( 0 x0B , v al u e ) return
7 | YoMoPi - Library

### 3.16 get_sample

Description: Takes one sample and calculates the active energy, apparent energy, reactive energy, VRMS and IRMS. The calculated values are the real values. (after adjusting with their factores)
Parameters: None.
Returns: A list of 7 elements [timestamp, active energy, apparent energy, reactive energy, period, VRMS, IRMS]

def get_sample ( s e l f ) :
aene r gy = s e l f . get_aenergy ( ) [ 1 ] ∗ s e l f . a c ti v e _ f a c t o r
appenergy = s e l f . get_appenergy ( ) [ 1 ] ∗ s e l f . a p p a r e n t_ f a c t o r r e n e r g y = math . s q r t ( appenergy ∗ appenergy − aene r gy ∗ aene r gy ) i f s e l f . debug :
pr int " Ac ti ve ␣ ene r gy : ␣%f ␣W, ␣Apparent ␣ ene r gy : ␣%f ␣VA, ␣ R e a c ti v e ␣Energy : ␣%f ␣ var " % ( aenergy , appenergy , r e n e r g y )
pr int "VRMS: ␣%f ␣IRMS: ␣%f "
%( s e l f . get_vrms ( ) [ 1 ] ∗ s e l f . vrms_ factor , s e l f . get_irms ( ) [ 1 ] ∗ s e l f . i rm s_ f a c t o r ) sample = [ ]
sample . append ( time . time ( ) ) sample . append ( aene r gy )
sample . append ( appenergy )
sample . append ( r e n e r g y )
sample . append ( s e l f . ge t_pe ri od ( ) [ 1 ] )
sample . append ( s e l f . get_vrms ( ) [ 1 ] ∗ s e l f . v rms_ fac tor ) sample . append ( s e l f . get_irms ( ) [ 1 ] ∗ s e l f . i rm s_ f a c t o r ) return sample

### 3.17 get_vrms

Description: Reads the VRMS register depending on if the active lines is 1 or 3. Parameters: None.
Returns: A list of 2 elements [timestamp, Phase A VRMS] or 4 elements [timestamp, Phase A VRMS, Phase B VRMS, Phase C VRMS]

def get_vrms ( s e l f ) :
i f s e l f . a c t i v e _ l i n e s == 1 : avrms = [ time . time ( ) , s e l f . re ad_ 2 4bi t ( 0 x2C ) ] return avrms
e l i f s e l f . a c t i v e _ l i n e s == 3 : vrms = [ ]
vrms . append ( time . time ( ) )
vrms . append ( s e l f . re ad_ 2 4bi t ( 0 x2C ) ) vrms . append ( s e l f . re ad_ 2 4bi t ( 0 x2D ) ) vrms . append ( s e l f . re ad_ 2 4bi t ( 0 x2E ) ) return vrms
return 0

### 3.18 get_irms

Description: Reads the IRMS register depending on if the active lines is 1 or 3.

8 | YoMoPi - Library

Parameters: None.
Returns: A list of 2 elements [timestamp, Phase A IRMS] or 4 elements [timestamp, Phase A IRMS, Phase B IRMS, Phase C IRMS]

def get_irms ( s e l f ) :
i f s e l f . a c t i v e _ l i n e s == 1 : ai rm s = [ time . time ( ) , s e l f . re ad_ 2 4bi t ( 0 x29 ) ] return ai rm s
e l i f s e l f . a c t i v e _ l i n e s == 3 :
i rm s = [ ]
i rm s . append ( time . time ( ) )
i rm s . append ( s e l f . re ad_ 2 4bi t ( 0 x29 ) ) i rm s . append ( s e l f . re ad_ 2 4bi t ( 0 x2A ) ) i rm s . append ( s e l f . re ad_ 2 4bi t ( 0 x2B ) ) return vrms
return 0

### 3.19 start_sampling

Description: Starts a sampling programm that takes a number of samples depending on the parameters.
Parameters: nr_samples - this are the number of samples that will be taken, integer greater then 0
samplerate - this is the time between each sample, integer greater then 0
Returns: A list of samples (each sample is a list of 7 elements)

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

for j in range ( 0 , s am pl e r a t e ) : time . s l e e p ( 1 )

s ample s . append ( s e l f . get_sample ( ) ) return s ample s

### 3.20 close

Description: Closes the SPI connection. Parameters: None.
Returns: Nothing.

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

## 4 OPMODE

The general configuration of the ADE7754 is defined by writing to the OPMODE register (0x0A).


Abbildung 1: OPMODE

10 | YoMoPi - Library

## 5 MMODE

The configuration of the period and peak measurements made by the ADE7754 are defined by writing to the MMODE register (0x0B).


Abbildung 2: MMODE

## 6 Examples

To use the YoMoPi library you first need to import the library.

import yomopi

When the library is correcty imported you can create a new YoMoPi object and initialize is with the init_yomopi function.

yomo = yomopi . YoMoPi ( )
yomo . init_yomopi ( )

To test the implementation we start a short sampling. Therefor we call the start_-sampling function with 5 samples and a delay of 1 second between each sample.

yomo . s t a r t_ s am pli n g ( 5 , 1 )

If you want to switch the measurement to one phase change the line like this.

yomo . s e t _ l i n e s ( 1 )

11 | YoMoPi - Library

## Abbildungsverzeichnis

12 | YoMoPi - Library

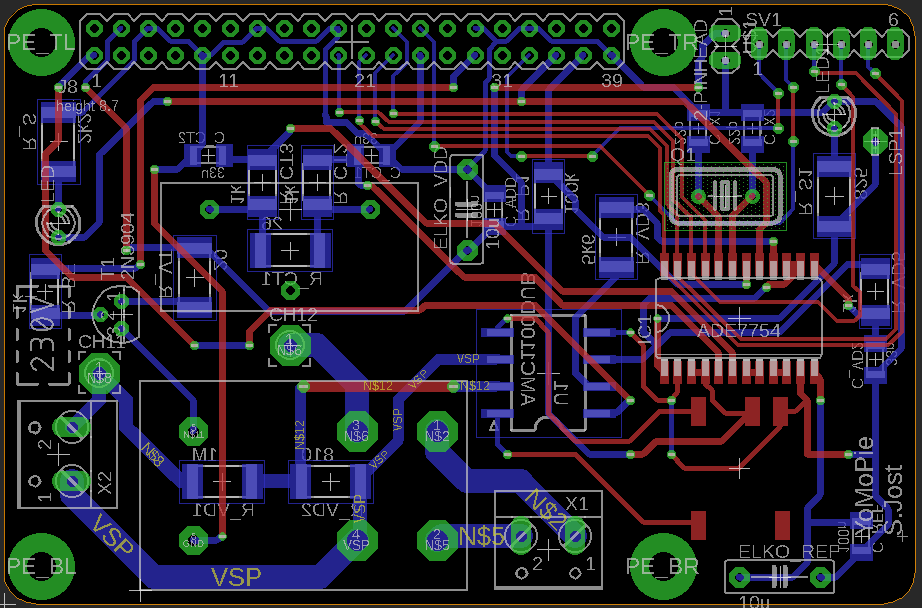
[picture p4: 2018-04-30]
Images/Eagle_YoMoPie_Board.PNG

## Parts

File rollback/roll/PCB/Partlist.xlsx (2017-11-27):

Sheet: RS online
at.rs-online.com | Requester | Item name | Product ID | Price | Quantity | Total Price | Link
1 |  | TES 1-0511 | 438-058 | 5.39 | 1 | 5.39 | https://at.rs-online.com/web/p/dc-dc-wandler-isoliert/0438058/?searchTerm=TES+1-0511
2 |  | CST-1020 | 2509216147 | 7.73 | 5 | 38.65 | https://at.rs-online.com/web/p/stromwandler/2509216147/?searchTerm=cst+1020 | https://www.mouser.at/ProductDetail/Triad-Magnetics/CST-1020/?qs=U28YatCw3SLIfLWnzZJMKA%3D%3D
3 |  | ADE7754ARZ | 496-9638 | 9.14 | 1 | 9.14 | https://at.rs-online.com/web/p/leistungsmess-ics/4969638/
4 |  | G4W-2212P-US-TV5 5DC | 683-9090 | 3.15 | 1 | 3.15 | https://at.rs-online.com/web/p/monostabile-relais/6839090/
5 |  | R_VD2 (820 Ohm) | 755-1255 | 0.256 | 10 | 2.56 | https://at.rs-online.com/web/p/smd-widerstande/7551255/
6 |  | R_VD1 (1 MOhm) | 679-2427 | 0.191 | 25 | 4.775 | https://at.rs-online.com/web/p/smd-widerstande/6792427/
7 |  | LED 1 und 2 | 247-1404 | 0.12 | 5 | 0.6 | https://at.rs-online.com/web/p/leds-sichtbares-licht/2471404/
8 |  | Quarz LFXTAL003169 10MHz | 226-1746 | 1.31 | 1 | 1.31 | https://at.rs-online.com/web/p/quarzmodule/2261746/
9 |  | R_BE (1 kOhm) | 679-2395 | 0.163 | 25 | 4.075 | https://at.rs-online.com/web/p/smd-widerstande/6792395/
10 |  | R_CT1 (27 Ohm) | 842-9519 | 0.18 | 1 | 0.18 | https://at.rs-online.com/web/p/smd-widerstande/8429519/
11 |  | R_CT2 (1 kOhm) | 679-2395 | 0.163 | 25 | 4.075 | https://at.rs-online.com/web/p/smd-widerstande/6792395/
12 |  | R_CT3 (1 kOhm) | 679-2395 | 0.163 | 25 | 4.075 | https://at.rs-online.com/web/p/smd-widerstande/6792395/
13 |  | R_P1 (100 kOhm) | 679-2389 | 0.158 | 25 | 3.95 | https://at.rs-online.com/web/p/smd-widerstande/6792389/
14 |  | R_S (2,2 kOhm) | 679-2433 | 0.191 | 25 | 4.775 | https://at.rs-online.com/web/p/smd-widerstande/6792433/
15 |  | R_S1 (680 Ohm) | 679-2459 | 0.197 | 25 | 4.925 | https://at.rs-online.com/web/p/smd-widerstande/6792459/
16 |  | R_VD3 (5,6 kOhm) | 871-0828 | 0.618 | 10 | 6.18 | https://at.rs-online.com/web/p/smd-widerstande/8710828/
17 |  | R_VD5 (1 kOhm) | 679-2395 | 0.163 | 25 | 4.075 | https://at.rs-online.com/web/p/smd-widerstande/6792395/
18 |  | R_VT (20 Ohm) | 755-1126 | 0.221 | 10 | 2.21 | https://at.rs-online.com/web/p/smd-widerstande/7551126/
19 |  | Isolationsverstärker AMC1100DUB | 817-5786 | 4.84 | 1 | 4.84 | https://at.rs-online.com/web/p/trennverstarker/8175786/
20 |  | Leiterplattenklemme für 230V 2-polig | 361-7667 | 0.5 | 5 | 2.5 | https://at.rs-online.com/web/p/leiterplatten-printklemmen/3617667/
21 |  | Leiterplattenklemme für 230V 2-polig | 361-7667 | 0.5 | 5 | 2.5 | https://at.rs-online.com/web/p/leiterplatten-printklemmen/3617667/
22 |  | C_CT1 (33nF) | 669-8445 | 0.046 | 25 | 1.15 | https://at.rs-online.com/web/p/keramik-multilayer-kondensatoren/6698445/
23 |  | C_CT2 (33nF) | 669-8445 | 0.046 | 25 | 1.15 | https://at.rs-online.com/web/p/keramik-multilayer-kondensatoren/6698445/
24 |  | C_REF (100nF) | 669-8408 | 0.069 | 25 | 1.725 | https://at.rs-online.com/web/p/keramik-multilayer-kondensatoren/6698408/
25 |  | C_VDD (100nF) | 669-8408 | 0.069 | 25 | 1.725 | https://at.rs-online.com/web/p/keramik-multilayer-kondensatoren/6698408/
26 |  | C_VD3 (33nF) | 669-8445 | 0.046 | 25 | 1.15 | https://at.rs-online.com/web/p/keramik-multilayer-kondensatoren/6698445/
27 |  | ELKO_REF (10µF) | 228-6717 | 0.184 | 5 | 0.92 | https://at.rs-online.com/web/p/aluminium-elektrolytkondensatoren/2286717/
28 |  | ELKO_VDD (10µF) | 228-6717 | 0.184 | 5 | 0.92 | https://at.rs-online.com/web/p/aluminium-elektrolytkondensatoren/2286717/
29 |  | C_X1 (22pF) | 669-8482 | 0.124 | 25 | 3.1 | https://at.rs-online.com/web/p/products/6698482/?grossPrice=Y&matchtype=&gclsrc=aw.ds
30 |  | C_X2 (22pF) | 669-8482 | 0.124 | 25 | 3.1 | https://at.rs-online.com/web/p/products/6698482/?grossPrice=Y&matchtype=&gclsrc=aw.ds
31 |  | Pinleiste für RF-Interface | 547-3166 | 0.74 | 1 | 0.74 | https://at.rs-online.com/web/p/leiterplatten-header/5473166/
32 |  | Leiterplattenbuchse für GPIO | 254-6110 | 6.82 | 1 | 6.82 | https://at.rs-online.com/web/p/leiterplatten-buchsen/2546110/
 |  |  |  |  | SUMME | 136.435

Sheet: Conrad
Conrad.at | Requester | Item name | Product ID | Price | Quantity | Total Price | Link
 |  |  |  |  |  | 0
 | Christoph | Arduino Uno |  |  |  | 0
 |  |  |  |  |  | 0
 |  |  |  |  |  | 0
 |  |  |  |  |  | 0
 |  |  |  |  |  | 0
 |  |  |  |  |  | 0
 |  |  |  |  |  | 0
 |  |  |  |  |  | 0
 |  |  |  |  |  | 0
 |  |  |  |  |  | 0
 |  |  |  |  |  | 0
 |  |  |  |  |  | 0
 |  |  |  |  |  | 0
 |  |  |  |  |  | 0
 |  |  |  |  |  | 0
 |  |  |  |  |  | 0
 |  |  |  |  |  | 0
 |  |  |  |  |  | 0
 |  |  |  |  |  | 0
 |  |  |  |  |  | 0
 |  |  |  |  | Total | 0

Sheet: Exp-tech
 |  | Arrived:
Exp-tech.de | Requester | Item name | Product ID | Price | Quantity | Total Price
1 |  |  |  |  | 1 | 0
2 |  |  |  |  | 1 | 0
3 |  |  |  |  | 1 | 0
4 |  |  |  |  | 1 | 0
5 |  |  |  |  | 1 | 0
6 |  |  |  |  |  | 0
7 |  |  |  |  |  | 0
8 |  |  |  |  |  | 0
9 |  |  |  |  |  | 0
10 |  |  |  |  |  | 0
11 |  |  |  |  |  | 0
12 |  |  |  |  |  | 0
13 |  |  |  |  |  | 0
14 |  |  |  |  |  | 0
15 |  |  |  |  |  | 0
16 |  |  |  |  |  | 0
 |  |  |  |  |  | 0
 |  |  |  |  |  | 0
 |  |  |  |  |  | 0
 |  |  |  |  |  | 0
 |  |  |  |  |  | 0
 |  |  |  |  |  | 0
 |  |  |  |  |  | 0
 |  |  |  |  |  | 0
 |  |  |  |  |  | 0
 |  |  |  |  | Total | 0 | €

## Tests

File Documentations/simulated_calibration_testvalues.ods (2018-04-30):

Waveformgenerator | Vpp | Ipp(real) | Vpp(real) | Imax(real) | Vmax(real) | Ueff(real) | Ieff(real) | Ueff(measured) | Ieff(measured) | P(real) | P(measured) | Error[%] | Vpp to Ipp(real) calculation | Vpp to Vpp(real) calculation
 | 0,01 | 0,384615385 | 12,35567901 | 0,192307692 | 6,177839506 | 4,368392208 | 0,135982073 | 4,326638673 | 0,13540246 | 0,594023029 | 0 | -100 | 38,46153846 | 1235,567901
 | 0,02 | 0,769230769 | 24,71135802 | 0,384615385 | 12,35567901 | 8,736784416 | 0,271964147 | 8,632078 | 0,273893 | 2,376092118 | 0 | -100
 | 0,03 | 1,153846154 | 37,06703704 | 0,576923077 | 18,53351852 | 13,10517662 | 0,40794622 | 13,099072 | 0,409456 | 5,346207265 | 5,16096 | -3,465022132 | All values labeled „real“ are the calculated values by hand
 | 0,04 | 1,538461538 | 49,42271605 | 0,769230769 | 24,71135802 | 17,47356883 | 0,543928293 | 17,602238 | 0,550552 | 9,504368471 | 7,74144 | -18,54861242
 | 0,05 | 1,923076923 | 61,77839506 | 0,961538462 | 30,88919753 | 21,84196104 | 0,679910367 | 21,646688 | 0,686115 | 14,85057574 | 12,9024 | -13,11851992
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

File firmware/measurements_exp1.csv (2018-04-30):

t | , |  | d | , | a | , | b
1521213089.307249 | 0.0004150867462158203 | 1915852679.376373 | 1211478.7489228535
1521213090.308437 | 1.001188039779663 | 794535.8219683343 | 39.80323617206825
1521213091.309544 | 1.0011069774627686 | 794600.441843773 | 39.625849078127445
1521213092.310657 | 1.001112937927246 | 794595.142566632 | 40.528658119238706
1521213093.311376 | 1.0007190704345703 | 794908.4514591655 | 40.110977382062835
1521213094.312481 | 1.0011048316955566 | 794609.959929465 | 29.728481031895203
1521213095.313589 | 1.001108169555664 | 0.0 | 0.07224394146348899
t | , |  | d | , | a | , | b
1521213175.189396 | 0.00022101402282714844 | 3597907516.331232 | 2749610.1931743687
1521213176.190665 | 1.0012691020965576 | 0.0 | 0.0
1521213177.191807 | 1.0011420249938965 | 0.0 | 0.0
1521213178.192895 | 1.0010879039764404 | 0.0 | 0.0
1521213179.194005 | 1.0011100769042969 | 0.0 | 0.0
1521213180.19509 | 1.0010850429534912 | 0.0 | 0.0
1521213181.196171 | 1.0010809898376465 | 0.0 | 0.0
1521213182.197248 | 1.0010769367218018 | 0.0 | 0.03612309770957133
t | , |  | d | , | a | , | b
1521213208.293472 | 0.00025200843811035156 | 0.0 | 286.99039025165564
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

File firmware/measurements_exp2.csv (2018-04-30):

t | , |  | d | , | a | , | b
1521214988.464898 | 0.0016231536865234375 | 484716091.1984531 | 3809656.5406843936
1521214989.466333 | 1.0014348030090332 | -22.72687940504371 | 55.01798722637664
1521214990.467615 | 1.001281976699829 | -22.5409286546722 | 54.363416167150596
1521214991.468895 | 1.0012800693511963 | -22.493616610778982 | 54.69500460094679
1521214992.470167 | 1.0012719631195068 | -22.82528627766263 | 55.074290333862315
1521214993.471456 | 1.0012891292572021 | -22.25664031380445 | 53.98419139944058
1521214994.472727 | 1.0012710094451904 | -22.920018839570965 | 55.405830665905015
1521214995.474018 | 1.001291036605835 | -22.25659791736733 | 53.98408856552926
1521214996.475244 | 1.0012259483337402 | -22.77897775018286 | 55.313609173001204
1521214997.476469 | 1.0012249946594238 | -22.400138749661316 | 54.12972217941412
1521214998.477763 | 1.0012938976287842 | -22.63536894978921 | 55.12043819572101
1521214999.478978 | 1.0012149810791016 | -22.495078904757822 | 54.22497967567938
1521215000.480261 | 1.0012831687927246 | -22.493546982474406 | 54.83689980148497
1521215001.481548 | 1.0012869834899902 | -22.777589218733713 | 55.026109505547964
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

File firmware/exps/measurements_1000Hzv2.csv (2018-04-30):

t | , |  | d | , | a | , | b
1521232915.822 | 0.0007760524749755859 | 974929.8667255742 | 756596.736
1521232915.824994 | 0.002994060516357422 | 49.24950554419494 | 147.456
1521232915.827857 | 0.0028629302978515625 | 38.62895302864757 | 110.59200000000001
1521232915.830553 | 0.0026960372924804688 | 54.6936054672798 | 147.456
1521232915.833135 | 0.0025818347930908203 | 42.83465398171577 | 110.59200000000001
1521232915.835744 | 0.0026090145111083984 | 56.51789186000183 | 147.456
1521232915.838319 | 0.0025751590728759766 | 57.26092867549301 | 147.456
1521232915.840966 | 0.002646923065185547 | 41.781342818230954 | 110.59200000000001
1521232915.843553 | 0.0025870800018310547 | 56.99707774619851 | 147.456
1521232915.846182 | 0.0026290416717529297 | 42.065518089054144 | 110.59200000000001
1521232915.848782 | 0.002599954605102539 | 42.5361272781293 | 110.59200000000001
1521232915.851464 | 0.0026819705963134766 | 41.23535140616944 | 110.59200000000001
1521232915.854236 | 0.0027718544006347656 | 53.1975993999656 | 147.456
1521232915.85714 | 0.002904176712036133 | 50.773769856662014 | 147.456
1521232915.860199 | 0.003058910369873047 | 48.20540067217459 | 147.456
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

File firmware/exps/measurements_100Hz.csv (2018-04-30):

t | , |  | d | , | a | , | b
1521232780.895518 | 0.010565996170043945 | 442968.25596715446 | 468040.0896
1521232780.905699 | 0.010180950164794922 | 54.31320171982577 | 55.296
1521232780.9159 | 0.010200977325439453 | 54.20657083718974 | 55.296
1521232780.926192 | 0.01029205322265625 | 60.89047408154188 | 62.668800000000005
1521232780.936412 | 0.010220050811767578 | 64.92648737479588 | 66.3552
1521232780.946587 | 0.010174989700317383 | 72.46002420788714 | 73.728
1521232780.956775 | 0.010187864303588867 | 83.22372331768504 | 84.7872
1521232780.967001 | 0.010226011276245117 | 90.12311595439603 | 92.16
1521232780.977177 | 0.010175943374633789 | 90.56654170239685 | 92.16
1521232780.98742 | 0.01024317741394043 | 93.57096545995391 | 95.8464
1521232780.997595 | 0.010174989700317383 | 90.57503025985893 | 92.16
1521232781.00779 | 0.010195016860961914 | 94.01298821486868 | 95.8464
1521232781.017974 | 0.01018381118774414 | 90.49657176569742 | 92.16
1521232781.02821 | 0.010236024856567383 | 90.03495135210677 | 92.16
1521232781.038376 | 0.010166168212890625 | 83.40133492232646 | 84.7872
1521232781.048541 | 0.010164976119995117 | 94.29082652881435 | 95.8464
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

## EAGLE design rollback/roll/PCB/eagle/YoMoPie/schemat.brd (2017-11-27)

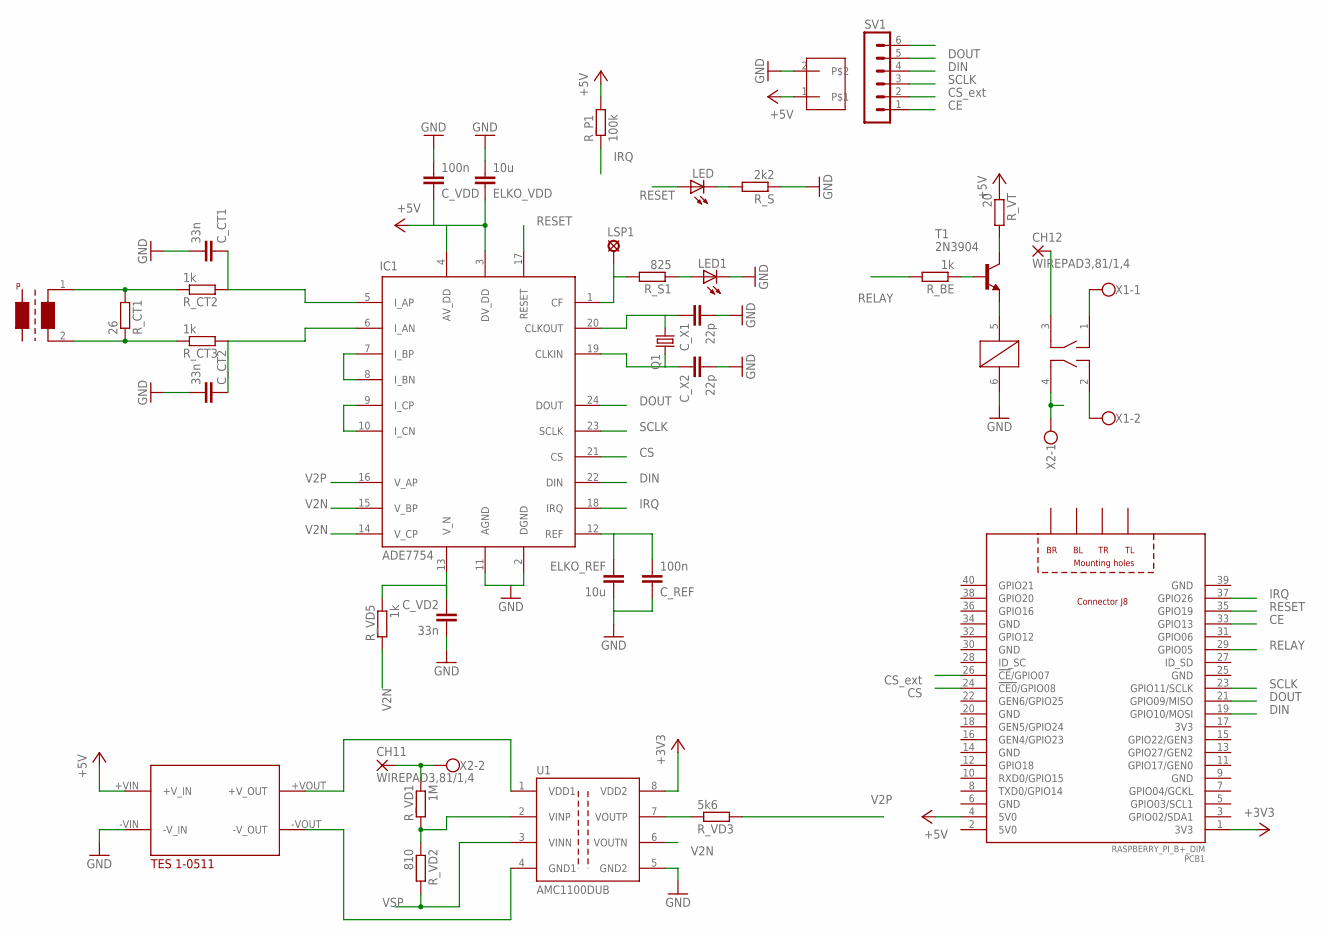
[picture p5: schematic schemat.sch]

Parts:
CH11, CH12: WIREPAD3,81/1,4; 3,81/1,4
C_CT1, C_CT2: 33n; C1206K
C_REF: 100n; C1206K
C_VD2: 33n; C1206K
C_VDD: 100n; C1206K
C_X1, C_X2: 22p; C1206K
ELKO_REF: 10u; C7.5B3
ELKO_VDD: 10u; C7.5B3
IC1: ADE7754; SO24L
LED, LED1: LED3MM
LSP1: LSP10
PCB1: RASPBERRY_PI_B+_DIM; RASPBERRY_PI_BPLUS_DIM
Q1: CRYSTALHC18U-V; HC18U-V
R_BE: 1k; R2010
R_CT1: 26; R2512
R_CT2, R_CT3: 1k; R2010
R_P1: 100k; R2010
R_S: 2k2; R2512
R_S1: 825; R2512
R_VD1: 1M; R2512
R_VD2: 810; R2512
R_VD3: 5k6; R2512
R_VD5: 1k; R2010
R_VT: 20; R2512
SV1: MA06-1
T1: 2N3904; TO92
U1: AMC1100DUB; DIP8-GULLWING
U$1: 2-PINHEAD
U$2: CST-1020; CST1020
U$3: TES1-0511; 0511
U$4: G4W-2212P-US-TV5
X1, X2: W237-102

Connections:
3V3: PCB1.17 (3V3)
5V0: PCB1.2 (5V0)
+3V3: PCB1.1 (3V3), U1.8 (VDD2)
+5V: C_VDD.1, ELKO_VDD.1, IC1.3 (DV_DD), IC1.4 (AV_DD), PCB1.4 (5V0), R_P1.2, R_VT.1, U$1.1, U$3.+VIN (+V_IN)
CE: PCB1.33 (GPIO13), SV1.1
CS: IC1.21 (CS), PCB1.24 (!CE0!/GPIO08)
CSE: PCB1.26 (!CE!/GPIO07), SV1.2
DIN: IC1.22 (DIN), PCB1.19 (GPIO10/MOSI), SV1.4
DOUT: IC1.24 (DOUT), PCB1.21 (GPIO09/MISO), SV1.5
GND: C_CT1.2, C_CT2.2, C_REF.1, C_VD2.2, C_VDD.2, C_X1.2, C_X2.2, ELKO_REF.2, ELKO_VDD.2, IC1.2 (DGND), IC1.11 (AGND), LED1.K (C), PCB1.6 (GND), PCB1.9 (GND), PCB1.14 (GND), PCB1.20 (GND), PCB1.25 (GND), PCB1.30 (GND), PCB1.34 (GND), PCB1.39 (GND), R_S.1, U1.5 (GND2), U$1.2, U$3.-VIN (-V_IN), U$4.6
IRQ: IC1.18 (IRQ), PCB1.37 (GPIO26), R_P1.1
unnamed: C_REF.2, ELKO_REF.1, IC1.12 (REF)
unnamed: U$4.1, X1.1
unnamed: C_VD2.1, IC1.13 (V_N), R_VD5.1
unnamed: R_BE.1, T1.2 (B)
unnamed: U$4.2, X1.2
unnamed: CH12.1, U$4.3
unnamed: IC1.1 (CF), LSP1.MP, R_S1.2
unnamed: CH11.1, R_VD1.1, X2.2
unnamed: R_VT.2, T1.1 (C)
unnamed: LED1.A, R_S1.1
unnamed: T1.3 (E), U$4.5
unnamed: R_VD1.2, R_VD2.1, U1.2 (VINP)
unnamed: IC1.7 (I_BP), IC1.8 (I_BN)
unnamed: IC1.9 (I_CP), IC1.10 (I_CN)
unnamed: R_CT1.2, R_CT2.1, U$2.1
unnamed: R_VD3.1, U1.7 (VOUTP)
unnamed: LED.K (C), R_S.2
unnamed: U1.1 (VDD1), U$3.+VOUT (+V_OUT)
unnamed: U1.4 (GND1), U$3.-VOUT (-V_OUT)
unnamed: R_CT1.1, R_CT3.1, U$2.2
unnamed: C_CT2.1, IC1.6 (I_AN), R_CT3.2
unnamed: C_CT1.1, IC1.5 (I_AP), R_CT2.2
unnamed: C_X1.1, IC1.20 (CLKOUT), Q1.1
unnamed: C_X2.1, IC1.19 (CLKIN), Q1.2
RELAY: PCB1.29 (GPIO05), R_BE.2
RESET: IC1.17 (RESET), LED.A, PCB1.35 (GPIO19)
SCLK: IC1.23 (SCLK), PCB1.23 (GPIO11/SCLK), SV1.3
V2N: IC1.14 (V_CP), IC1.15 (V_BP), R_VD5.2, U1.6 (VOUTN)
V2P: IC1.16 (V_AP), R_VD3.2
VSP: R_VD2.2, U1.3 (VINN), U$4.4, X2.1

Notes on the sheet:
RESET
IRQ
DOUT
DIN
SCLK
RELAY
V2P
CS_ext

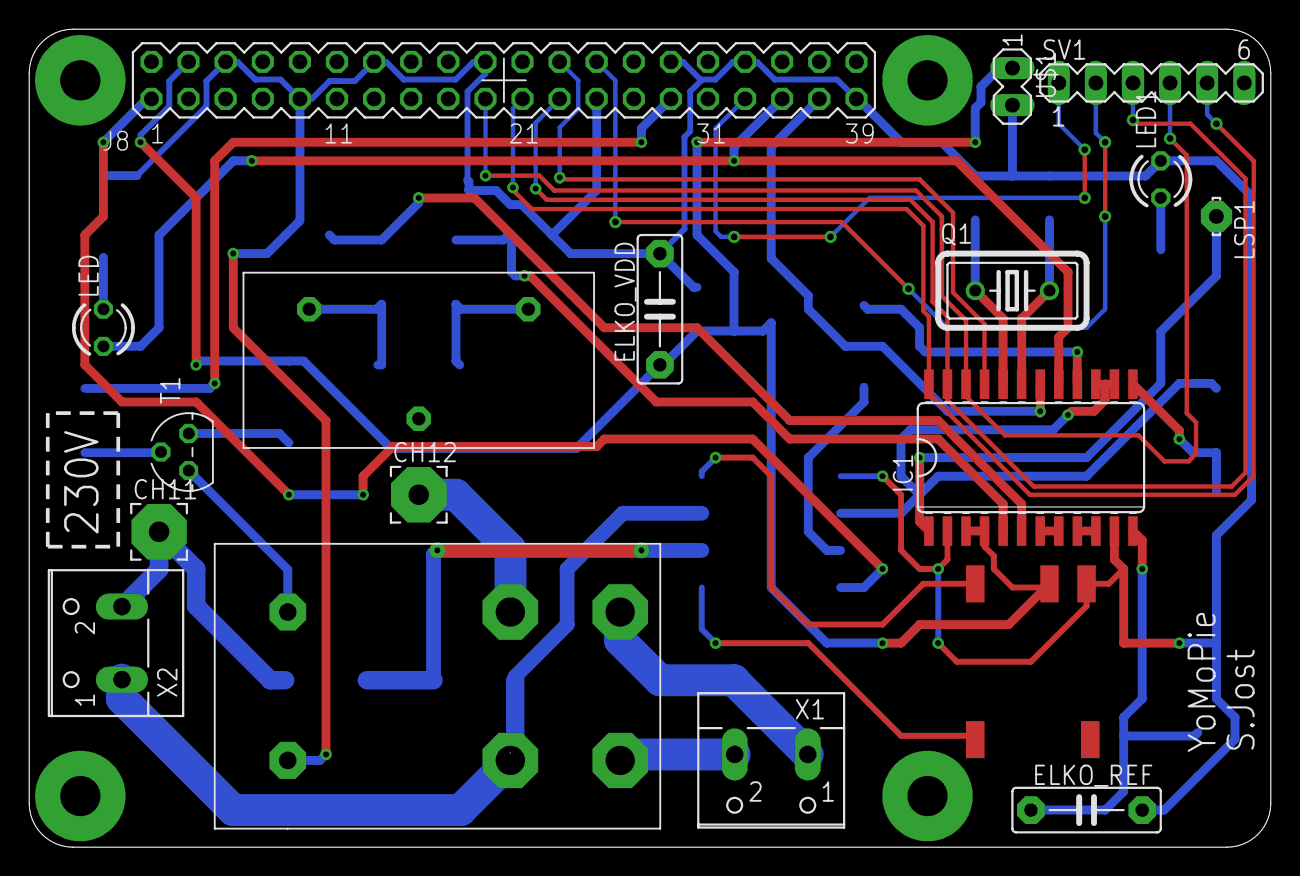
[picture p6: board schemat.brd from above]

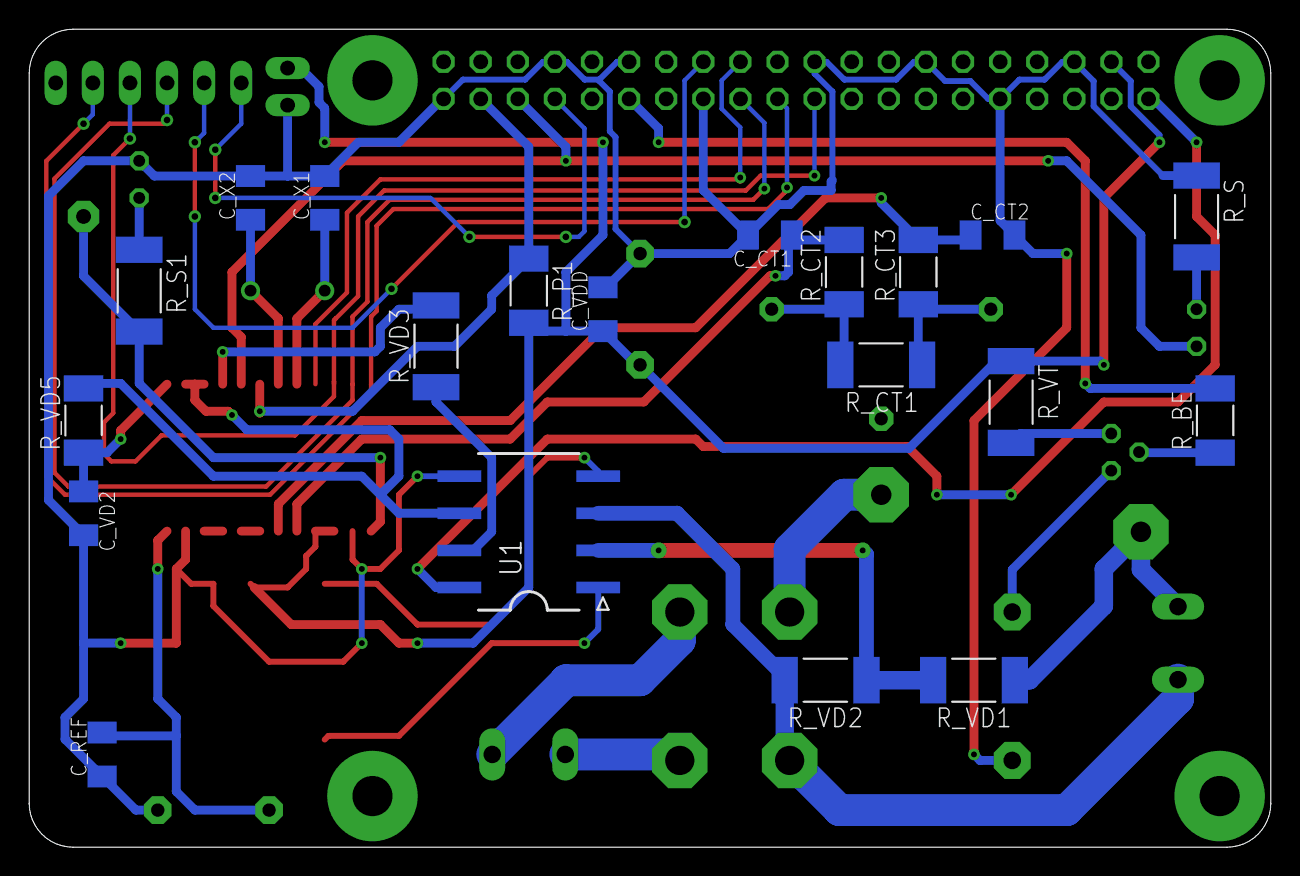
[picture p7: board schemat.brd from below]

Board: 2 copper layers, 85.0 x 56.0 mm, 38 parts (20 on the bottom side), 39 nets.

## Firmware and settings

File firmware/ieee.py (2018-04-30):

# Measurement script for the IEEE paper

import YoMoPie
import csv, time
from datetime import datetime

def write_to_CSV(destination, data):
    datafile = open(destination, 'a')
    csv_writer = csv.writer(datafile)
    csv_writer.writerow(data)


yomo = YoMoPie.YoMoPie()  ##create a new YoMoPie Object
yomo.set_lines(1)  ##set number of lines to 1. Following commands will do the same
time.sleep(1)

measurement_selector = 2

'''
Measurement #1: Measurement accuracy

Measurement #2: Maximal sampling freuency

Measurement #3: Measurement accuracy vs Sampling freuency

'''


if measurement_selector == 1:
    yomo.sample_intervall = 1
    a = time.time()
    write_to_CSV('/home/pi/Schreibtisch/YoMoPie/firmware/measurements_exp1.csv','t, d, a,b')
    while(1):
        sample = []
        b = time.time()
        time_diff = b - a
        sample.append(b)
        sample.append(time_diff)
        #sample.append(yomo.read_24bit(0x01))
        sample.append(yomo.active_power_LSB * yomo.read_24bit(0x02) *  3600/time_diff)
        sample.append(yomo.apparent_power_LSB * yomo.read_24bit(0x05)*  3600/time_diff)
        #write_to_CSV('/home/pi/Schreibtisch/YoMoPie/firmware/measurements_exp1x.csv',sample)
        a = b
        print(sample)
        duration = time.time() - b
        if(yomo.sample_intervall-duration)>0:
            time.sleep(yomo.sample_intervall-duration)


if measurement_selector ==2:
    yomo.sample_intervall = 0.001
    a = time.time()
    energy_old = 0
    write_to_CSV('exps/measurements_1000Hzv2.csv','t, d, a,b')
    while(1):
        sample = []
        b = time.time()
        time_diff = b - a
        sample.append(b)
        sample.append(time_diff)
        energy = yomo.read_24bit(0x04)
        #print(energy)
        #sample.append(yomo.apparent_power_LSB * (energy-energy_old) *  3600/time_diff)
        temp = yomo.read_24bit(0x05)
        sample.append(yomo.apparent_power_LSB * temp *  3600/time_diff)
        sample.append(yomo.apparent_power_LSB * temp*  3600/yomo.sample_intervall)
        write_to_CSV('exps/measurements_1000Hzv2.csv',sample)
        a = b
        energy_old = energy
        duration = time.time() - b
        #print(sample)
        if(yomo.sample_intervall-duration)>0:
			time.sleep(yomo.sample_intervall-duration)


if measurement_selector == 3:
    yomo.sample_intervall = 1
    a = time.time()
    write_to_CSV('/home/pi/Schreibtisch/YoMoPie/firmware/measurements_exp3.csv','t,d,a,r,p,r')
    while(1):
        sample = []
        b = time.time()
        time_diff = b - a
        sample.append(b)
        sample.append(str(datetime.now()))
        sample.append(time_diff)
        active = yomo.read_24bit(0x02)
        apparent = yomo.read_24bit(0x05)
        sample.append(active)
        sample.append(yomo.active_power_LSB * active *  3600/time_diff)
        sample.append(apparent)
        sample.append(yomo.apparent_power_LSB * apparent *  3600/time_diff)
        write_to_CSV('/home/pi/Schreibtisch/YoMoPie/firmware/measurements_exp3.csv',sample)
        a = b
        print(sample)
        duration = time.time() - b
        if(yomo.sample_intervall-duration)>0:
            time.sleep(yomo.sample_intervall-duration)

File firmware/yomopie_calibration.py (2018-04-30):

import YoMoPie
import time


##INIT
yomo = YoMoPie.YoMoPie()  ##create a new YoMoPie Object

yomo.set_lines(1)  ##set number of lines to 1. Following commands will do the same

yomo.write_8bit(0x0B, 0x10)  ##MMODE 0x10
yomo.write_8bit(0x0D, 0x24)  ##WATMODE 0x24
yomo.write_8bit(0x0E, 0x24)  ##VAMODE 0x24
yomo.write_16bit(0x13, [0x00, 0xC8])   ##LINCYC 0d200
yomo.write_16bit(0x0F, [0x04, 0x00])   ##IRQEN 0x0400




Cf = 0.000013171
CfVA= 0.000010045


CfV = 0.000047159
CfI = 0.000010807


watt = 1026.2
VA = 56.04 
measurement = 1	     ## 1...Watt/h calibration, 2...VA/h calibration, 3...Cf and CfVA testing
pe=0.1
    
'''
        Wh/LSB constant = (W * Accumulation time(s)/3600)/(LAENERGY/4)
        
        with
        
        Accumulation time(s) = LINCYC[15:0] * Line Period/(2*#of phase selected)
        
        and
        
        Line Period(s) = Period Register * 2.4 * 10^-6
        
        
        Simulated load with 100mVpp @ 50Hz on the input of the AMC1100 and the output of the CST1020:
        calculated Load: 61,778Vpp and 1,92App
        Ueff = 61,778/sqrt(2) = 43,68V
        Ieff = 1,92/sqrt(2) = 1,375A
        -> load = 59,30W/h
        
        -> Cf = 0.000014
        
        -> Cf(VRMS) = 0.000047159
        -> Cf(IRMS) = 0.000010807
        
        
        VRMS = VRMS0 + 64*VRMSOS
        VRMSOS = 1/64*(V1*VRMS2 - V2*VRMS1)/(V2-V1)
        
        IRMS2 = IRMS02 + 32768 * IRMSOS
        IRMSOS = 1/32768*(I12*IRMS22 - I22*IRMS12)/(I22-I12)
        
        
        
        Measurements 11.4.2018
        
        Cf(Wh/LSB) = 0.000013292   for 56.83W Lamp
        Cf(Wh/LSB) = 0.000013050   for 1025.2W Heater
        -> Cf(Wh/LSB) = 0.000013171
        
        
        Cf(VA/LSB) = 0.00001024   for 56.04VA Lamp
        Cf(VA/LSB) = 0.00000985   for 1025.2VA Heater
        -> Cf(VA/LSB) = 0.000010045
'''

##MEASUREMENTS
while True:
	if masurement == 1:
		print("--------------------------")
		period = yomo.get_period()[1] * 0.0000024
		print("Line Period = %f s" %(period))
		linecycles = yomo.read_16bit(0x13)
		print("Linecycles = %f" %(linecycles))
		atime = linecycles*period/2
		print("Accumulation time = %f s" %(atime))
		laenergy = yomo.get_laenergy()
		print("LAPPENERGY = %d" %(laenergy[1]))
		cf = watt*(atime/3600)/((laenergy[1]+10))
		print("Wh/LSB const = %f" %(cf))
		print("Wh/LSB const *1000 = %f" %(cf*1000))
		print("--------------------------")
	elif measurement == 2:		
		period = yomo.get_period()[1] * 0.0000024
		print("Line Period = %f s" %(period))
		linecycles = yomo.read_16bit(0x13)
		print("Linecycles = %f" %(linecycles))
		atime = linecycles*period/2
		print("Accumulation time = %f s" %(atime))
		lappenergy = yomo.get_lappenergy()
		print("LAPPENERGY = %d" %(lappenergy[1]))
		cf = VA*(atime/3600)/((lappenergy[1]+10))
		print("Wh/LSB const = %f" %(cf))
		print("Wh/LSB const *1000 = %f" %(cf*1000))
		print("--------------------------")
	elif measurement == 3:	
		print("VRMS = %f V" %(yomo.get_vrms()[1]*CfV))
		print("IRMS = %f A" %(yomo.get_irms()[1]*CfI))
		print("Aenergy = %d" %yomo.read_24bit(0x01))
		raen=yomo.read_24bit(0x02)
		print("RAenergy = %d" %raen)
		print("VAenergy = %d" %yomo.read_24bit(0x04))
		print("RVAenergy = %d" %yomo.read_24bit(0x05))
		raven=yomo.read_24bit(0x05)
		print("%f Watt/h, %f VA/h" %((raen*Cf*3600/pe), (raven*CfVA*3600/pe)))
		print("RVAenergy = %d" %raven)    
		print("%f VA/h" %(raven*CfVA*3600/pe))
    time.sleep(pe)    
        
yomo.close()   

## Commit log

2017-11-27 PCB_Pie
    added PCB data of the single-phase YoMoPie
    [Partlist.xlsx, schemat.brd, schemat.sch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]
2018-02-12 first sample test
2018-02-16 Update on description
    Edited ReadMe file and fixed errors
    [YoMoPie.py]
2018-03-15 calibration file updated
2018-03-15 added simulated calibration
2018-03-15 simulations and testing the error
    [simulated_calibration_testvalues.ods]
2018-03-16 Final calibration version
2018-03-16 calibration finished
2018-03-27 eagle board figure
2018-04-19 calibration file update and chip reset function
    [YoMoPie.py, yomopie_calibration.py]
2018-06-20 measurement test 1
    [fancy_10Hz.csv]
2018-06-20 10 min meas
    [final_fancy_10Hz.csv]
